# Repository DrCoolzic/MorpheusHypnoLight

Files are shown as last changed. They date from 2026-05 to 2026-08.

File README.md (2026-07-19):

# Morpheus HypnoLight

A low-cost Audio-Visual Stimulation (AVS) / Flicker Light Stimulation (FLS) device built around an ESP32-S3.

The device uses rhythmic light variation to influence brain activity and induce altered states of consciousness. It is controlled remotely via Bluetooth Low Energy or Wi-Fi, and can drive multiple LED groups with independent frequencies, waveforms, brightness, and phase modulation.

## Repository Structure

```text
MorpheusHypnoLight/
├── doc/                        # Project documentation
│   ├── MHLSpecification.md     # Product specification and features
│   ├── HardwarePrototype.md    # Prototype hardware, pinout, wiring, power budget
│   ├── SoftwareArchitecture.md # Firmware architecture and component design
│   ├── SoftwareSetup.md        # ESP-IDF + VS Code installation guide
│   └── images/                 # Diagrams, schematics, photos
├── firmware/                   # ESP-IDF firmware project
├── sim/                        # Simulation and PC-side tools
└── .venv/                      # Python virtual environment (for PC-side tools)
```

## Documentation

|Document|What you will find|
|---|---|
|[doc/MHLSpecification.md](doc/MHLSpecification.md)|Project objectives, features, LED architecture, oscillator design, sequence engine, real-time mode|
|[doc/HardwarePrototype.md](doc/HardwarePrototype.md)|Bill of materials, power supply, power budget, thermal design, ESP32-S3 pinout, wiring, main/control electronics, enclosure|
|[doc/SoftwareArchitecture.md](doc/SoftwareArchitecture.md)|Firmware layout, component responsibilities, data flow, build/flash instructions|
|[doc/SoftwareSetup.md](doc/SoftwareSetup.md)|Step-by-step installation of ESP-IDF, VS Code extension, and Hello World flash|

## Quick Start

1. Set up the development environment: follow [doc/SoftwareSetup.md](doc/SoftwareSetup.md).
2. Review the hardware prototype: [doc/HardwarePrototype.md](doc/HardwarePrototype.md).
3. Build and flash the firmware from the `firmware/` directory:

   ```bash
   cd firmware
   idf.py set-target esp32s3
   idf.py build
   idf.py -p PORT flash monitor
   ```

   In VS Code, use the ESP-IDF extension commands: **Build your Project**, **Flash your Project**, **Monitor your Device**.

## Hardware at a Glance

- **MCU**: ESP32-S3-DevKitC-1 (N16R8 module, 8MB PSRAM, 16MB flash)
- **LED drivers**: 3× SparkFun PicoBuck (AL8805, 9 channels total) for the prototype; final PCB will use AL8860 LED drivers
- **LEDs**: 32× 1W cold white (PB1..PB4 peripheral banks) + 4× 3W warm white (CG central group)
- **Power**: 24V / 5A supply, 5V buck converter for the ESP32
- **Cooling**: PWM-controlled fan driven by a TMP36 temperature sensor
- **Control interface**: 4× Adafruit NeoRotary 4 (I2C rotary encoders) + 1× I2C OLED display

## Status

This project is currently in the **hardware prototype and firmware architecture** phase. The specification and hardware documentation are in place; the firmware is under development. Once the prototype is validated, a dedicated `HardwarePCB.md` document will cover the final PCB design and production files.

## License

- Firmware and documentation: [MIT License](LICENSE)
- Hardware designs and production files: [CERN Open Hardware Licence v2 — Permissive](LICENSE-HARDWARE)

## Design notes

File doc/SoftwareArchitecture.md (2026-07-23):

# Software Architecture

## Overview

The Morpheus HypnoLight firmware is an [ESP-IDF](https://docs.espressif.com/projects/esp-idf/en/latest/esp32s3/index.html) project located in the `firmware/` directory of the repository. It is structured as a set of ESP-IDF components, each responsible for a distinct part of the device behavior.

The firmware implements two main operating modes described in the product specification:

- **Player Mode**: the `sequence` component advances stored steps and sends parameters to the `led_engine`.
- **Editor Mode**: commands from the `comms` layer or local controls write parameters directly into the `led_engine`.

Both modes share the same `led_engine` signal generation pipeline, which contains per oscillator a frequency modulator, a brightness modulator, and an oscillator.

## Repository Layout

```text
firmware/
├── CMakeLists.txt          # Project declaration
├── sdkconfig               # Generated menuconfig, committed to git
├── sdkconfig.defaults      # Optional baseline configuration
├── main/                   # Application entry point
│   ├── CMakeLists.txt
│   └── main.c              # app_main(): initialization
└── components/             # Application components
    ├── oscillator/         # Software oscillator engine (LUT + DDS)
    ├── led_control/        # Fixed LEDC channel output
    ├── modulator/          # Generic static/linear/LFO value generator
    ├── led_engine/         # Per-oscillator control chain
    ├── sequence/           # Sequence engine (steps, playback)
    └── comms/              # BLE / Wi-Fi communication layer
```

## Components

### `oscillator`

Responsible for generating the five low-frequency signals that drive the four peripheral banks (PB1..PB4) and the central group (CG).

- **Waveforms**: sine, square, triangle, custom.
  - **Sine** and **custom** are pre-computed into a 64-sample LUT when static parameters change.
  - **Square** and **triangle** are generated directly from the phase accumulator and duty cycle each tick.
- **Static parameters per oscillator**: waveform and phase. They are applied at a sequence-step boundary through `oscillator_set_static()`; sine and custom rebuild the LUT, while square and triangle only store the new waveform and phase.
- **Dynamic parameters per oscillator**: frequency and duty cycle. Both are updated on the fly through `oscillator_set_frequency()` and `oscillator_set_duty_cycle()` without rebuilding any LUT.
- **Output**: normalized instantaneous waveform values `osc_values[5]` in the range `[0.0, 1.0]`. At 0 Hz, an oscillator returns a constant `1.0` regardless of waveform, phase, or duty cycle.
- **Implementation**: Direct Digital Synthesis (DDS) phase accumulator updated by `oscillator_tick()` at 1 kHz. Sine and custom use a 64-sample LUT; square and triangle are computed from phase and duty. The component is independent of LEDC and brightness control.
- **Public API**:
  - `esp_err_t oscillator_init(void)`
  - `esp_err_t oscillator_set_static(uint8_t oscillator_id, const oscillator_static_config_t *config)`
  - `esp_err_t oscillator_set_frequency(uint8_t oscillator_id, float frequency_hz)`
  - `esp_err_t oscillator_set_duty_cycle(uint8_t oscillator_id, float duty_cycle)`
  - `esp_err_t oscillator_tick(float osc_values[OSCILLATOR_COUNT])`

### `led_control`

Converts the normalized oscillator waveform and current brightness into the duty cycle written to the five fixed LEDC hardware channels, applying a gamma correction so that brightness ramps appear perceptually linear. It does not evaluate step timing, interpolation, or LFOs.

- **PB1–PB4**: LEDC channels 0–3 at a common carrier frequency and 10-bit resolution. Each channel controls the two LED sub-groups in its peripheral bank.
- **CG**: LEDC channel 4, using the same configuration as the peripheral banks.
- **Fixed mapping**: API oscillator IDs 0–3 map to PB1–PB4 / LEDC channels 0–3; ID 4 maps to CG / LEDC channel 4.
- **Duty calculation**: `final_duty = osc_value × gamma(current_brightness × global_brightness)`, where `gamma(x) = x^2.2` approximates the human eye response so that linear brightness ramps look perceptually smooth. All inputs are normalized to `[0.0, 1.0]`, and out-of-range values are clamped; invalid oscillator IDs and non-finite input values return an error.
- **LED off condition**: a `current_brightness` of `0.0` turns the oscillator off regardless of waveform, frequency, phase, or duty cycle.
- **Global brightness multiplier**: configurable at runtime through `led_control_set_global_brightness()`. The default is 1.0 (no attenuation). A single setting scales the overall lamp brightness; the test application sets it to 0.5 to limit eye strain.
- **Public API**:
  - `esp_err_t led_control_init(void)`
  - `esp_err_t led_control_update(uint8_t oscillator_id, float osc_value, float current_brightness)`
  - `esp_err_t led_control_set_global_brightness(float brightness)`
  - `float led_control_get_global_brightness(void)`
  - `esp_err_t led_control_all_off(void)`

### `sequence`

Step sequencer / playback engine. The realtime parameter evaluation previously implemented here has moved to the `led_engine` component. `sequence` now focuses on storing and advancing steps, then dispatching per-oscillator modulator configurations to `led_engine`.

- **Player mode**: reads a stored sequence and advances from step to step. Each step carries duration, static oscillator configuration, and modulator settings for frequency, brightness, and duty cycle.
- **Editor mode**: future commands from `comms` will write step data and playback commands into `sequence`.
- **Playback control**: play, pause, seek, loop, and tempo will be managed here.
- **Public data types**:
  - `sequence_step_t` with `duration_ms` and per-oscillator `sequence_oscillator_step_t`
  - `sequence_oscillator_step_t` with `oscillator_static_config_t` and `modulator_config_t` for `frequency_modulator`, `brightness_modulator`, and `duty_modulator`
- **Public API**:
  - `esp_err_t sequence_init(void)`
  - `esp_err_t sequence_load(const sequence_step_t *steps, uint32_t step_count)`
  - `esp_err_t sequence_play(void)`
  - `esp_err_t sequence_pause(void)`
  - `esp_err_t sequence_seek(uint32_t position_ms)`
  - internal timer drives `sequence_tick()` every `SEQUENCE_STEP_TICK_PERIOD_MS`
  - `bool sequence_is_playing(void)`
  - `uint32_t sequence_get_current_step(void)`

### `modulator`

Generic time-varying value generator used by `led_engine` for frequency and brightness. It supports three modes: `static`, `linear`, and `lfo`. The LFO has no LUT and supports sine (or a triangle approximation) and square with a fixed 50% duty cycle.

```c
/** @brief Modulator operating modes. */
typedef enum {
  MODULATOR_MODE_STATIC,
  MODULATOR_MODE_LINEAR,
  MODULATOR_MODE_LFO,
} modulator_mode_t;

/** @brief LFO waveforms supported by the modulator. */
typedef enum {
  MODULATOR_LFO_WAVEFORM_SINE,
  MODULATOR_LFO_WAVEFORM_SQUARE,
} modulator_lfo_waveform_t;

/** @brief Static mode configuration: a constant value. */
typedef struct {
  float value;
} modulator_static_config_t;

/** @brief Linear mode configuration: ramp from start to end over a duration. */
typedef struct {
  float start_value;
  float end_value;
  uint32_t duration_ms;
} modulator_linear_config_t;

/** @brief LFO mode configuration. */
typedef struct {
  modulator_lfo_waveform_t waveform;
  float frequency_hz;
  float low;
  float high;
} modulator_lfo_config_t;

/** @brief Complete modulator configuration. */
typedef struct {
  modulator_mode_t mode;
  modulator_static_config_t static_config;
  modulator_linear_config_t linear_config;
  modulator_lfo_config_t lfo_config;
} modulator_config_t;

/** @brief Modulator runtime state. */
typedef struct {
  modulator_config_t config;
  float current_value;
  float start_value;
  uint32_t elapsed_ms;
  float lfo_phase;
} modulator_state_t;

/** @brief Initialize a modulator to static zero. */
esp_err_t modulator_init(modulator_state_t *state);

/** @brief Apply a new configuration and capture internal start state. */
esp_err_t modulator_set_config(modulator_state_t *state, const modulator_config_t *config);

/** @brief Compute the next value after delta_time_ms. */
esp_err_t modulator_evaluate(modulator_state_t *state, float delta_time_ms, float *value);
```

### `led_engine`

Encapsulates the per-oscillator signal chain: a frequency modulator, a brightness modulator, and an oscillator. It receives parameter updates from `sequence` in Player mode or directly from `comms` / local controls in Editor mode, then drives `led_control`.

- **Per oscillator**:
  - `frequency_modulator`: instance of the `modulator` component. Output is in Hz and forwarded to `oscillator_set_frequency()`.
  - `brightness_modulator`: instance of the `modulator` component. Output is normalized `[0.0, 1.0]` and forwarded to `led_control_update()` as `current_brightness`; `led_control` treats it as a perceptual brightness value and applies a gamma correction.
  - `duty_modulator`: instance of the `modulator` component. Output is normalized `[0.0, 1.0]` and forwarded to `oscillator_set_duty_cycle()`.
  - `oscillator`: generates the waveform from `oscillator_static_config_t`, the current frequency, and the current duty cycle.
- **Evaluation**: at each 1 kHz tick the engine evaluates the frequency, brightness, and duty modulators, applies them through `oscillator_set_frequency()` and `oscillator_set_duty_cycle()`, then calls `oscillator_tick()`, and passes `osc_value` and `brightness` to `led_control_update()`.
- **Public API**:
  - `esp_err_t led_engine_init(void)`
  - `esp_err_t led_engine_set_static(uint8_t oscillator_id, const oscillator_static_config_t *config)`
  - `esp_err_t led_engine_set_frequency(uint8_t oscillator_id, float frequency_hz)`
  - `esp_err_t led_engine_set_brightness(uint8_t oscillator_id, float brightness)`
  - `esp_err_t led_engine_set_duty_cycle(uint8_t oscillator_id, float duty_cycle)`
  - `esp_err_t led_engine_linear_frequency(uint8_t oscillator_id, float start_value, float end_value, uint32_t duration_ms)`
  - `esp_err_t led_engine_linear_brightness(uint8_t oscillator_id, float start_value, float end_value, uint32_t duration_ms)`
  - `esp_err_t led_engine_linear_duty_cycle(uint8_t oscillator_id, float start_value, float end_value, uint32_t duration_ms)`
  - `esp_err_t led_engine_set_frequency_modulator(uint8_t oscillator_id, const modulator_config_t *config)`
  - `esp_err_t led_engine_set_brightness_modulator(uint8_t oscillator_id, const modulator_config_t *config)`
  - `esp_err_t led_engine_set_duty_cycle_modulator(uint8_t oscillator_id, const modulator_config_t *config)`
  - `esp_err_t led_engine_tick(void)`
  - `esp_err_t led_engine_all_off(void)`

### `comms`

Communication layer for remote control and configuration.

- **Bluetooth Low Energy (BLE)**: primary control channel from the mobile/desktop application.
- **Wi-Fi**: optional web server interface for configuration and control.
- **Protocol**: to be defined (commands for play/pause/seek, parameter updates, sequence upload).
- **Public API** (to be defined):
  - `comms_init()`
  - `comms_register_command_handler(...)`
  - `comms_send_status(...)`

## Data Flow

The `led_engine` pipeline is shared by both Player and Editor modes. `sequence` (Player mode) and direct commands (Editor mode) both feed the same engine; the engine evaluates the frequency and brightness modulators, drives the oscillator, and writes the final duty cycle through `led_control`.

```mermaid
flowchart LR
    subgraph Sources
        RT([Realtime / Editor])
        SEQ([Sequence / Player])
    end

    RT -->|set parameters| CTRL
    SEQ -->|step parameters| CTRL

    subgraph CTRL[led_engine per oscillator]
        direction TB
        FM[frequency_modulator<br/>static / linear / lfo]
        BM[brightness_modulator<br/>static / linear / lfo]
        DM[duty_modulator<br/>static / linear / lfo]
        OSC[oscillator<br/>waveform, phase]
    end

    FM -- frequency_hz --> OSC
    DM -- duty_cycle --> OSC
    OSC -- osc_value --> LED
    BM -- brightness --> LED

    subgraph LED[led_control]
        direction TB
        PWM[LEDC PWM 1 kHz]
        DRV[AL8860 driver]
    end

    LED -->|PWM| LEDS[LED banks PB1..PB4 / CG]
```

## Runtime Architecture (FreeRTOS)

ESP-IDF includes FreeRTOS as the default real-time kernel. The firmware does not require a different RTOS such as Zephyr; FreeRTOS is sufficient for all timing, peripheral, and communication needs.

Proposed FreeRTOS tasks and timers:

|Task / Timer|Period|Responsibility|
|---|---|---|
|`led_engine_timer`|1 ms (1 kHz)|Call `led_engine_tick()` to evaluate frequency, brightness, and duty modulators, apply `oscillator_set_frequency()` / `oscillator_set_duty_cycle()`, advance the oscillator, and pass each waveform value and effective brightness to `led_control`.|
|`sequencer_task`|10–50 ms|Future sequence playback: advance stored steps and dispatch modulator configurations to `led_engine`.|
|`input_task`|50–100 ms|Poll I2C rotary encoders and update parameters or sequence.|
|`display_task`|100–250 ms|Refresh the OLED display with current status.|
|`comms_task`|event-driven|Handle BLE/Wi-Fi events and dispatch commands.|
|`fan_task`|1 s|Read TMP36 temperature, update fan PWM.|
|`watchdog_task`|1 s|Feed the watchdog and monitor safety thresholds (temperature, stack).|

**Inter-task communication:**

- `led_engine` protects its per-oscillator modulator configuration with a critical section. Modulator evaluation, frequency publication to `oscillator`, oscillator ticking, and LED output updates happen sequentially in the 1 kHz timer callback.
- `led_control` protects the global brightness multiplier with a critical section; the final output is scaled in `led_control_update()`.
- `comms` posts commands to a FreeRTOS queue consumed by `sequence` or `input_task`.

## Build, Flash and Monitor

All commands are run from the `firmware/` directory.

```bash
idf.py set-target esp32s3
idf.py build
idf.py -p PORT flash
idf.py -p PORT monitor
```

For Visual Studio Code, use the ESP-IDF extension commands:

- **ESP-IDF: Build your Project**
- **ESP-IDF: Flash your Project**
- **ESP-IDF: Monitor your Device**

> **Important:** Always use the **`UART`** USB port of the DevKitC-1 for flashing and monitoring. See [SoftwareSetup.md](SoftwareSetup.md) for the full environment setup.

## Important `sdkconfig` Settings

The following ESP-IDF configuration options will be required or important for the project. They are typically set via `idf.py menuconfig` and committed in `sdkconfig`:

- **LEDC**: 5 channels, 10-bit resolution, using a common carrier frequency for PB1..PB4 and CG.
- **I2C**: master mode on GPIO1 (SDA) / GPIO2 (SCL) for the QWIIC bus.
- **ESP Timer**: periodic task-dispatched callback at 1 kHz for `oscillator_tick()` and LEDC output updates. The application does not rely on the FreeRTOS tick rate for oscillator timing.
- **BLE / Wi-Fi**: enable as needed for the `comms` component.

## Testing

### Visual Hardware Test

The current `main` application includes a visual oscillator test using a single task-dispatched `esp_timer` callback at 1 kHz. The callback calls `led_engine_tick()`, which evaluates the frequency and brightness modulators, advances the oscillator, and updates `led_control`. Linear ramps are therefore evaluated each millisecond inside the modulators.

The test stages use full per-channel brightness values; the global brightness multiplier is set to 0.5 in `app_main()` (`led_control_set_global_brightness(0.5f)`), scaling the effective output to 50% to reduce eye strain:

- PB1: 2 Hz square waveform with 50% duty cycle (set dynamically via `led_engine_set_duty_cycle()`).
- PB2: 2 Hz square waveform with 25% duty cycle (set dynamically via `led_engine_set_duty_cycle()`).
- PB3: 0.25 Hz triangle waveform.
- PB4: 0.25 Hz sine waveform.
- CG: 0 Hz fixed output, independent of waveform and phase.
- PB1 and PB2: 2 Hz square waveforms with a 180-degree phase offset.
- PB1: linear brightness ramp from 0% to 100% over 4 seconds at 0 Hz.
- PB2: linear frequency ramp from 0 Hz to 2 Hz over 4 seconds at full per-channel brightness.

This validates the oscillator-to-LEDC pipeline on hardware, including waveforms, duty cycle, frequency, zero-frequency behavior, relative phase, and visible realtime linear ramps. It does not replace deterministic unit tests of individual LUT samples, DDS phase increments, or sequence tick interpolation.

### Deferred Unit Tests

A future ESP-IDF Unity test application will be separate from the production firmware. It will build and flash independently, then run Unity `TEST_CASE` functions over the serial monitor. The first oscillator unit tests should cover initialization, zero-frequency output, waveform phase, DDS phase advancement, custom LUT copying, and argument validation.

## TBD / Future Sections

- Sequence file format (JSON or binary).
- BLE/Wi-Fi command protocol.
- Error handling and safety (thermal shutdown, watchdog).
- Fan control algorithm.
- Calibration and factory settings.

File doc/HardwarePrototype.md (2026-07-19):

# Hardware Prototype

The prototype is built on a set of boards connected via QWIIC/STEMMA QT cables:

- **Main electronics**: ESP32-S3-DevKitC-1, 3× PicoBuck LED converters, 9 LED groups, temperature sensor, fan, 2× DC-DC converters (for 5V and 12V)
- **Control electronics**: 4× Adafruit NeoRotary 4 (I2C quad rotary encoder + NeoPixel ring), 1× I2C OLED display 128×64 SSD1306

## Components

The components used for the prototype are:

- [ESP32-S3-DevKitC-1 8MB PSRAM 16MB FLASH N16R8 42Pin](https://fr.aliexpress.com/item/1005007173771226.html) development board
- 3× [PicoBuck LED Driver](https://www.sparkfun.com/picobuck-led-driver.html)
- 32× [1W High Power cool white 6500K LED with 20mm star pcb](https://fr.aliexpress.com/item/1005003381591196.html) for the 8 peripheral groups
- 4× [3W High Power warm white LED with 20mm star pcb](https://fr.aliexpress.com/item/1005003381591196.html) for the central group
- [150×150 aluminum plate](https://www.amazon.fr/Plaque-aluminium-5083-150mm/dp/B07NYV688B/ref=sr_1_6?th=1) (or a [150×150×25mm Aluminum Heat Sink radiator](https://fr.aliexpress.com/item/32958588818.html))
- [ARCTIC TP-4 : High Performance Thermal Pad 100×100×0.5 mm](https://www.amazon.fr/ARCTIC-TP-4-thermique-performance-irrégularités/dp/B0FZV47ZNR/ref=sxin_10_pa_sp_search_thematic_sspa?th=1)
- [24V 5A 120W Power Supply](https://www.amazon.fr/Alimentation-Adaptateur-Transformateur-Convertisseur-Surveillance/dp/B0FWRG2X67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)
- [5A DC-DC Step Down Power Supply Buck Converter](https://fr.aliexpress.com/item/1005005921557535.html) for 5V ESP32 power
- [12V DC-DC Step Down Power Supply Buck Converter](https://fr.aliexpress.com/item/1005010319587802.html) for 12V fan power
- [TMP36 temperature sensor](https://fr.aliexpress.com/item/1005007666012953.html)
- [4-pin SM04B-SRSS-TB connector for QWIIC](https://fr.aliexpress.com/item/1005012597457629.html)
- [2.54 mm KF2510 3+1P KF2510-4AW Male Housing Connector White Straight Pin Header 4pin](https://fr.aliexpress.com/item/1005004714218238.html)
- 4× [Adafruit I2C Quad Rotary Encoder](https://learn.adafruit.com/adafruit-i2c-quad-rotary-encoder-breakout/arduino)
- [I2C OLED Display 128×64 SSD1306](https://fr.aliexpress.com/item/1005011852817482.html)

> **Note:** The PicoBuck uses the AL8805 LED driver, which is functionally equivalent to the AL8860 selected for the final product. The AL8860 is the recommended choice for the final PCB design.
>

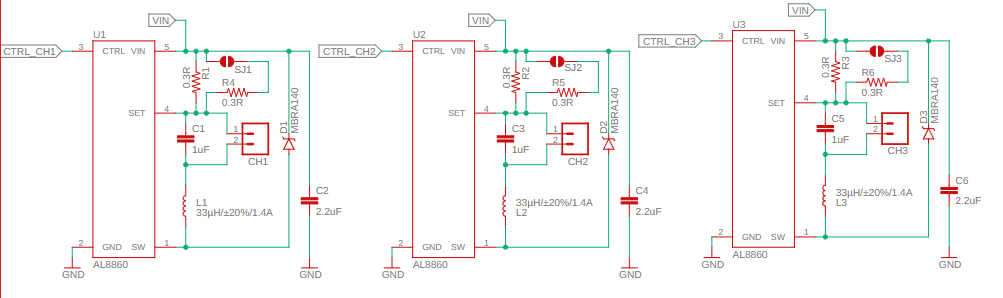
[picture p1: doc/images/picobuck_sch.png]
PicoBuck Schematic


## Power Supply

The prototype is powered by a 24V 5A 120W supply:

- 24V is used directly by the PicoBuck LED Buck Converters to power the LEDs.
- A 5V DC-DC buck converter provides power to the ESP32-S3-DevKitC-1.
- A 12V DC-DC buck converter provides power to the PWM fan.

> **Important — Power source conflict:** The ESP32-S3-DevKitC-1 can be powered either from the on-board USB port(s) or from the external `5V` pin, but these two sources are mutually exclusive. If the 5V DC-DC converter is connected to the DevKit `5V` pin while the USB cable is also plugged in, the USB 5V rail and the converter output will be in parallel. Depending on the converter design, this may cause backfeeding and could damage the converter or the USB port.
>
> **Always isolate the 5V DC-DC converter output (e.g., with a jumper) before connecting a USB cable for development.**

## Power Budget

|Component|Power|Notes|
|---|-----|-----|
|8 peripheral LED groups|~36W|4 × 1W cold white LEDs per group|
|Central LED group|~4.5W|4 × 3W warm white LEDs at ~330mA (default)|
|Central LED group (strap)|~9W|Same LEDs at ~660mA with current-doubling strap|
|LED driver losses|~4W|~10% buck converter losses at full LED power|
|ESP32-S3 + peripherals|~2.5W|Dev board at 5V, ~500mA peak|
|5V buck converter|~0.5W|Conversion losses|
|12V buck converter|~0.5W|Conversion losses for the fan|
|PWM fan|~1W|120mm fan at moderate speed|
|**Total (default)**|**~49W**|Corresponds to ~2.0A at 24V|
|**Total (central strap)**|**~54W**|Corresponds to ~2.3A at 24V|

The 24V / 5A / 120W supply leaves a comfortable margin (about 2.5× the expected maximum load).

## Thermal Considerations

At full brightness, the LEDs dissipate most of their consumed power as heat. The 150×150mm aluminum plate (or optional heatsink) combined with the PWM fan must keep the LED temperature below the rated maximum. The TMP36 temperature sensor located on the aluminum LED plate will increase the fan speed if the temperature exceeds a defined threshold. Exact thermal calculations will depend on the final plate thickness, heatsink choice, and ambient conditions, and will be validated during prototype testing.

## ESP32-S3 Pin selection

The following pins must **not** be used as general-purpose I/O:

- **GPIO0**: Strapping pin — boot mode selection (download vs. normal boot)
- **GPIO3**: Strapping pin — JTAG signal source selection
- **GPIO45**: Strapping pin — VDD_SPI voltage (3.3 V vs 1.8 V for flash/PSRAM)
- **GPIO46**: Strapping pin — ROM serial output enable
- **GPIO19**: USB D- (USB-JTAG); disables USB-JTAG if reconfigured
- **GPIO20**: USB D+ (USB-JTAG); disables USB-JTAG if reconfigured
- **GPIO26–GPIO32**: Reserved for internal SPI0/1 flash — never use
- **GPIO33–GPIO37**: Reserved for Octal flash/PSRAM — **this project uses an ESP32-S3R8 module**, so all five pins are unavailable externally.
- **GPIO43**: UART0 TX (wired to the on-board USB-to-UART bridge CP2102N) — avoid unless UART0 is not needed
- **GPIO44**: UART0 RX (same as above)
- **GPIO48**: On-board addressable RGB LED

> **Note on GPIO39–42:** These are **safe to use** as general-purpose I/O (they are JTAG pins only when the JTAG interface is actively enabled via software/OpenOCD, not by default in application code).

For the prototype we need 10 GPIO pins:

- 4 LEDC/PWM GPIO pins for the signals that control the 4 peripheral banks (PB1-PB4), each containing 2 LED sub-groups: GPIO4, GPIO5, GPIO6, GPIO7
- 1 LEDC/PWM GPIO pin for the signal that controls the central LED group (CG): GPIO15
- 2 I2C GPIO pins for the SDA/SCL signals that go to the QWIIC connector: GPIO1 (SDA), GPIO2 (SCL)
- 1 Analog GPIO pin connected to the TMP36 temperature sensor: GPIO16 (ADC2_CH5)
- 1 GPIO pin for fan tachometer input: GPIO17
- 1 GPIO pin to control the fan PWM: GPIO18

## Prototype wiring

The prototype consists of two electronics assemblies connected via QWIIC/STEMMA QT cables:

- **Main electronics**: ESP32-S3-DevKitC-1, PicoBuck converters, LED star groups, fan, temperature sensor
- **Control electronics**: 4× Adafruit NeoRotary 4 (I2C quad rotary encoder + NeoPixels), 1× I2C OLED display

### Main electronics

**Composed of**:

- An 15x15 cm aluminum plate with
  - [x] 36 (9x4) LEDs mounted with thermal pad
  - [ ] a temperature sensor
  - [x] One 6x9 cm prototype board with
    - [x] An ESP32-S3 devkit,
    - [x] A 5V DC-DC Buck converter
    - [x] A 5V Jumper so the converter can be isolated when a USB cable is plugged in for development
    - [ ] A 12V DC-DC Buck converter
    - [x] A 2 Pin power connector
    - [ ] A 4 pins QWIIC connector
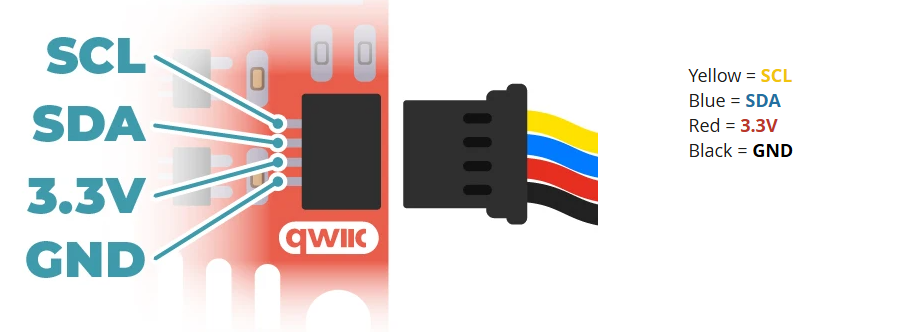
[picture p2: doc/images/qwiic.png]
QWIIC connector
    
    - [ ] A 4 pins PWM fan connector
    Fan connector
  - [x] Three PicoBuck boards
  - [x] Five 10 kΩ pull-down resistors on the LEDC/PWM control lines

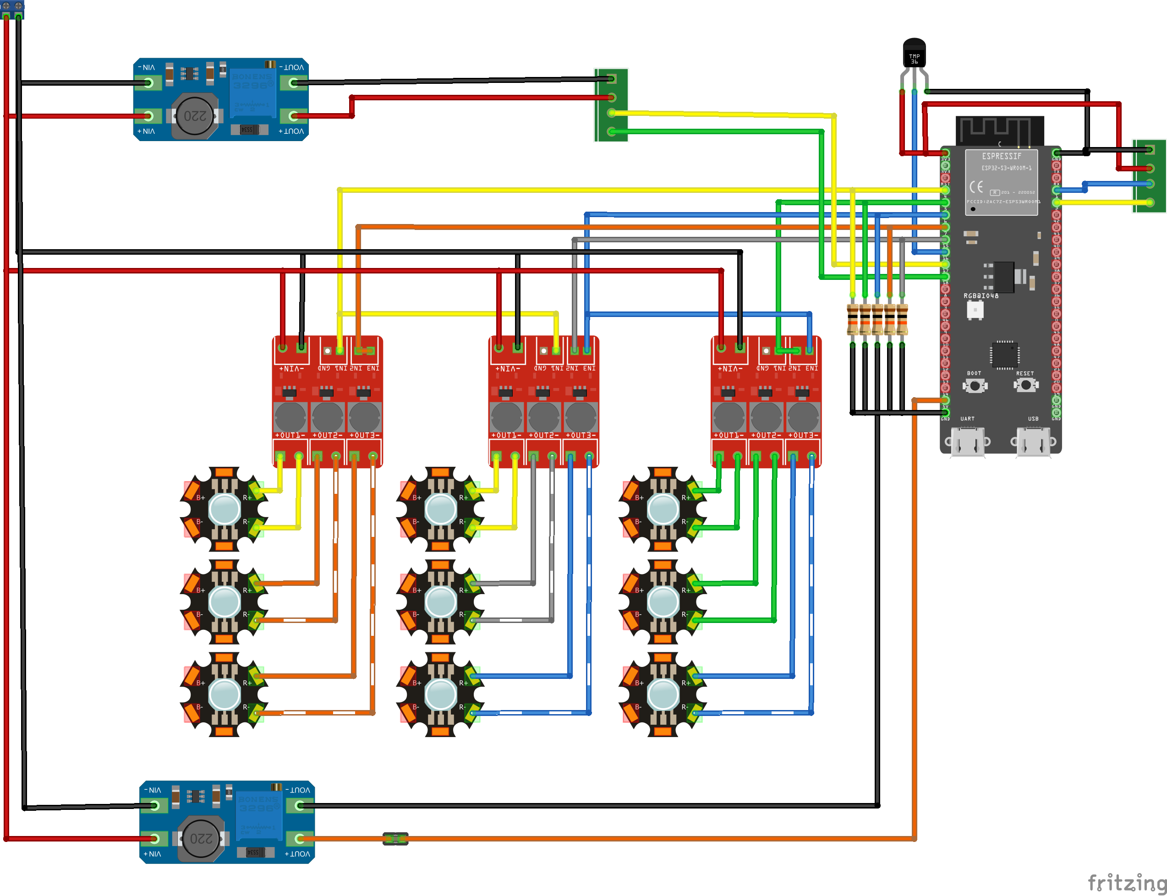
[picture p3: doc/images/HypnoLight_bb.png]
Main Electronics

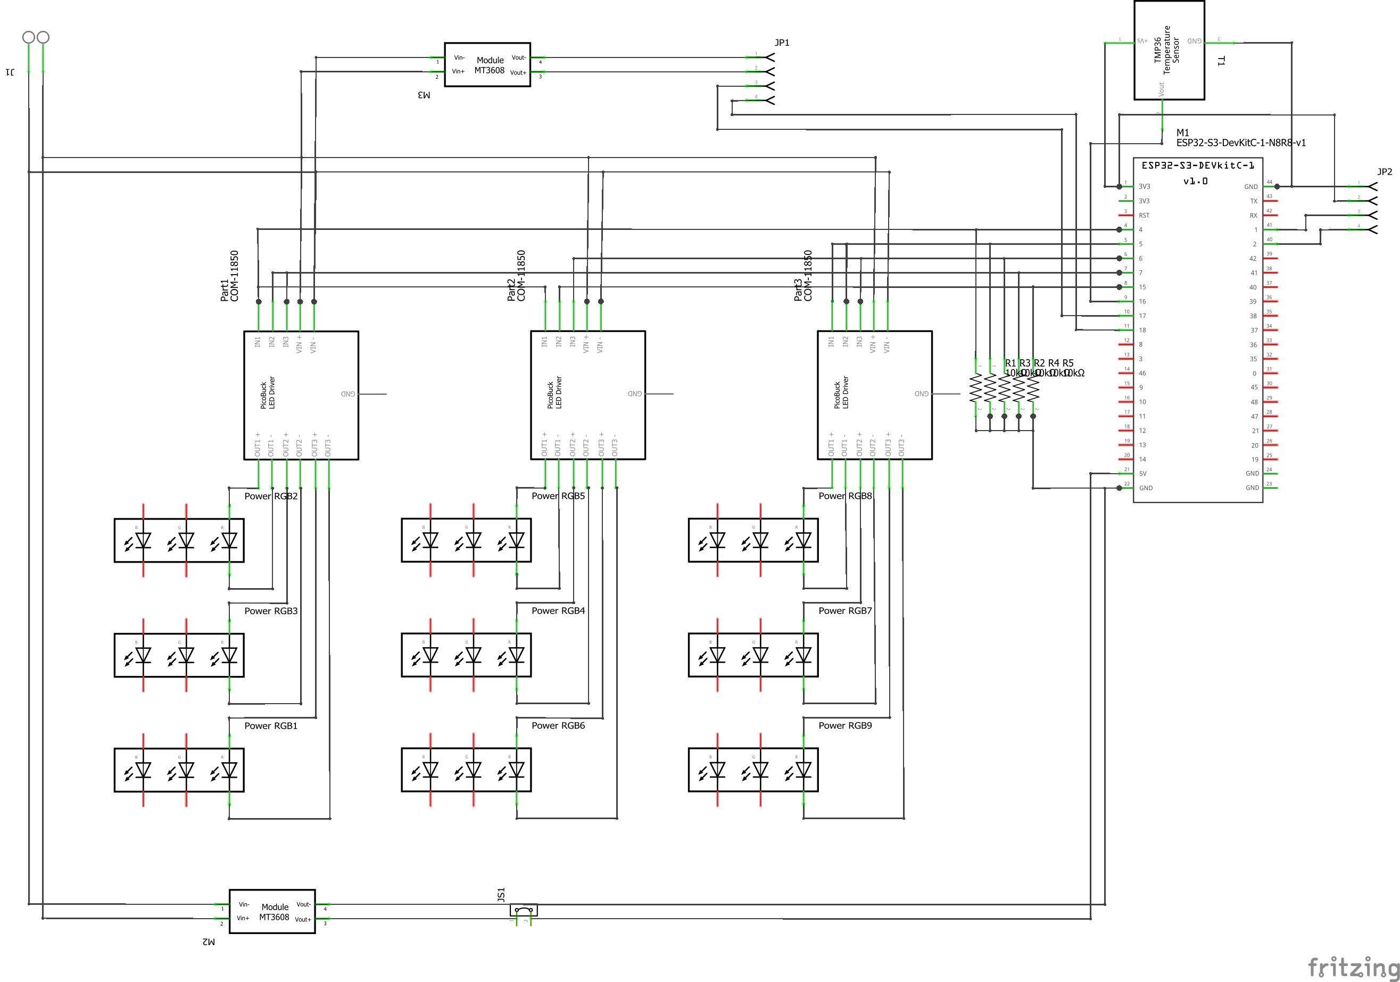
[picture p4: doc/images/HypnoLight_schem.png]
Main Schematic


> **Note1**: LED Groups are shown in the schematic as one LED but in fact each group contains 4 LEDs connected in series as shown below
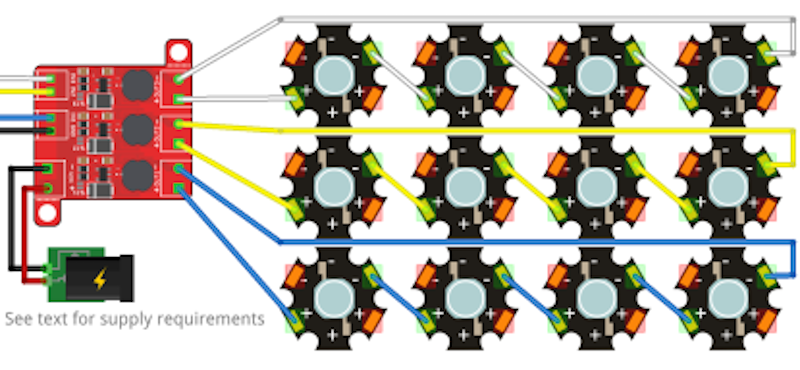
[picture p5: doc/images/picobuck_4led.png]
4LED


**Wiring**:

- [x] Connect the 24 V power supply to the input of the 3 PicoBuck converter (VIN+ / VIN−) using 18 AWG wires
- [ ] Connect the 24 V power supply to prototype board power connector
- [x] Connect the power connector to the 5V DC-DC converter inputs
- [ ] Connect the power connector to the 12V DC-DC converter inputs
- [x] Connect the 5V DC-DC converter GND output to the GND pins of the ESP32-S3-DevKitC-1
- [x] Connect the 5V DC-DC converter 5V output to the jumper input and the jumper output to the 5V pins of the ESP32-S3-DevKitC-1
- [x] Connect in series the 4 LEDs of each group of LEDs (nine) using 22 AWG wires
- [x] Connect the three outputs of the three PicoBuck the the nine group of LEDs using 22 AWG wires
- [x] Connect the inputs of the PicoBuck to the GPIO pins using 22 AWG wires
  - [x] GPIO4 to PicoBuck_1 IN1 and PicoBuck_2 IN1
  - [x] GPIO5 to PicoBuck_3 IN1 and IN2
  - [x] GPIO6 to PicoBuck_2 IN3 and PicoBuck_3 IN3
  - [x] GPIO7 to PicoBuck_1 IN2 and IN3
  - [x] GPIO15 to PicoBuck_2 IN2
  - [x] Connect one 10 kΩ pull-down resistor from each LEDC/PWM control line (GPIO4, GPIO5, GPIO6, GPIO7, GPIO15) to GND
  - [x] Connect the GND pins of the PicoBuck converters to the GND pin(s) of the ESP32-S3-DevKitC-1

> **PWM safety note:** During ESP32 reset and boot, the LEDC/PWM GPIOs are high impedance until the firmware configures them. The 10 kΩ pull-down resistors hold the PicoBuck inputs low during this interval, preventing an unintended full-brightness flash.

- [ ] For the QWIIC connector: Connect SDA to GPIO1, SCL to GPIO2, VCC to 3.3 V, GND to GND.
- [ ] For the PWM Fan Connector: Connect the 12V DC-DC converter outputs to the V+ and GND pins, TACH pin to GPIO17, PWM pin to GPIO18
- [ ] Connect the temperature sensor power and ground to the 3.3V and GND pins of the ESP32
- [ ] Connect the temperature sensor output to GPIO16

### Control electronics

The Control electronics is a standalone device connected to the Main electronics via a QWIIC/STEMMA QT cable. All components on this device communicate with the ESP32-S3 over the shared I2C bus (GPIO1/GPIO2).

**Components (to be connected in a later prototype phase):**

> **Note:** The NeoRotary encoders and OLED display are not connected in the first hardware bring-up phase. The initial firmware will be controlled and monitored via the serial interface.

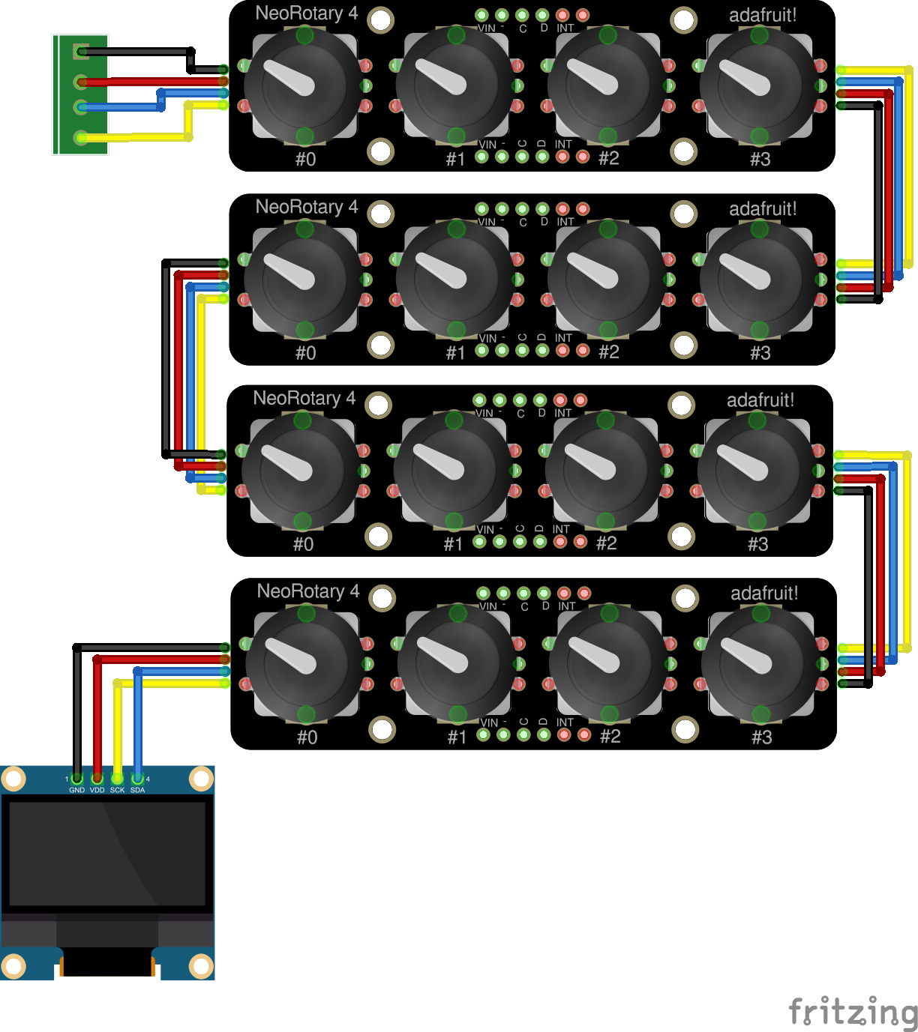
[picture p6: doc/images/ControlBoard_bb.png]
Control


**I2C addressing:**

The four NeoRotary 4 boards share the same I2C bus. Each board's address must be unique and set via the address jumpers on the board:

|Board|I2C Address|
|-----|---|
|NeoRotary #0|0x49 (default)|
|NeoRotary #1|0x4A|
|NeoRotary #2|0x4B|
|NeoRotary #3|0x4C|
|OLED display|0x3C (typical)|

**Wiring:**

- [ ] Mount the four NeoRotary 4 boards on the Control electronics board.
- [ ] Mount the OLED display on the Control electronics board.
- [ ] Chain all boards via their QWIIC connectors (daisy-chain): Main electronics → NeoRotary #0 → NeoRotary #1 → NeoRotary #2 → NeoRotary #3 → OLED.
- [ ] Set the I2C address jumpers on each NeoRotary 4 board according to the table above.
- [ ] Connect the first QWIIC connector of the chain to the QWIIC connector on the Main electronics.

## Enclosure Prototype

> **Note:** The enclosure will differ between the prototype and the final product.

The main prototype enclosure will be designed to hold the Main electronics, the LED plate, and the cooling fan.
The control enclosure will be designed to hold the Control electronics.

The current plan is to use FreeCAD with MCP to generate the enclosure and drive a 3D printer.

TBD.

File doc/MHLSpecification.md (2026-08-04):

# Morpheus HypnoLight Device

## Objective

The Morpheus HypnoLight Project is an ecosystem consisting of three main components: the Morpheus Player, the Morpheus Editor, and the Morpheus HypnoLight Device.
The objective of this project is to create an environment for visual and auditory stimulation often referred to as AVS (Audio-Visual Stimulation) or FLS (Flicker Light Stimulation).
Flicker Light Stimulation is a non-invasive technique that uses rhythmic light variation to influence brain activity and the state of consciousness.
It involves emitting rhythmic light pulses at specific frequencies, typically ranging from 3 Hz to 50 Hz.
These light pulses stimulate the visual system, leading to a phenomenon called "visual entrainment," in which brain activity synchronizes with the frequency of the light.
This synchronization can induce altered states of consciousness, like those experienced during deep meditation or under the influence of psychedelics, often accompanied by striking visual patterns and sensations beyond conscious control.

A stimulation session consists of both an acoustic component and a visual component.
The audio component is handled by the Morpheus Player / Editor, and the visual component is handled by the Morpheus HypnoLight device.

This specification describes the Morpheus HypnoLight Device, which generates light flashes controlled by the Morpheus Player or the Morpheus Editor.

## Operating Modes

The Morpheus HypnoLight Device can be controlled by two host applications, each corresponding to a distinct operating mode:

**Player Mode**

When controlled by the Morpheus Player, the device behaves like a video player: it loads and plays a sequence made of steps. Playback follows the timing defined in the sequence, and the Player handles the audio locally while sending the necessary timing and parameter data to the HypnoLight device. When playback is paused, the LEDs turn off. This mode is intended for end users who are not concerned with the internal content of the sequence.

**Editor Mode**

When controlled by the Morpheus Editor, the device supports both sequence playback and realtime editing. While a sequence is playing, the behavior is similar to Player mode. When the Editor is paused, playback stops and the current LED state is frozen (the LEDs remain on). The user then enters a realtime editing state in which any parameter — such as oscillator frequency, waveform, duty cycle, phase, or brightness — can be modified directly, for example through potentiometers or on-screen controls. Changes are applied immediately and are reflected on the LEDs in real time. This mode is intended for users who create and edit sequences and therefore need a detailed understanding of how the Morpheus HypnoLight device works.

---

## Main Features

- Two modes of operation as described above
- Bluetooth Low Energy connectivity, used to connect to the control applications and potentially to a sound system
- 4 peripheral LED banks (PB1..PB4, cold white), each containing 2 sub-groups of 4 LEDs and driven by one of 4 LEDC hardware channels
- 1 central LED group (CG, warm white) driven by a dedicated LEDC hardware channel
- 5 oscillators with sine, triangle, square, and custom waveforms, each with controllable frequency, duty cycle, brightness, and phase; oscillators 1-4 drive banks PB1-PB4 and oscillator 5 drives the central group CG
- Generic modulator for frequency, brightness, and duty cycle with static, linear, and simple LFO modes
- Step-based sequence engine with modulator-based frequency, brightness, and duty cycle control
- Capability to freely pause and seek loaded sequences
- A gamma correction is applied to compensate for the fact that the brightness perceived by the human eye follows the Weber–Fechner law, making variations in brightness appear linear.
- Low-cost hardware (target: under $100)
- Low-noise cooling using a large PWM temperature controlled fan
- Compact and easy to carry with [tripod mounting threads](https://www.amazon.fr/ruthex-Lot-pannes-%C3%A0-souder/dp/B0F1B8GC7Z?th=1) - [Hexagonal Insert for Tripod Mounting](https://www.amazon.fr/QUARKZMAN-Entra%C3%AEnement-Hexagonal-Connecteur-Fixation/dp/B0G138HB36/ref=sr_1_49_sspa)
- WiFi web server interface

---

## LED PCB

The LEDs are placed on a front panel PCB with an aluminum substrate for heat dissipation. In addition to the LEDs, the PCB contains temperature sensors that automatically activate the fan if the device overheats.

Numerous experiments have shown that the position of the LEDs on the PCB has no effect on the user's perception. For instance, a diode that lights up in the top left or bottom right corner of the board is perceived by the user in exactly the same way. Consequently, the LEDs have been arranged into four peripheral banks (PB1..PB4) plus one central group (CG), with each bank containing two sub-groups of four LEDs each:

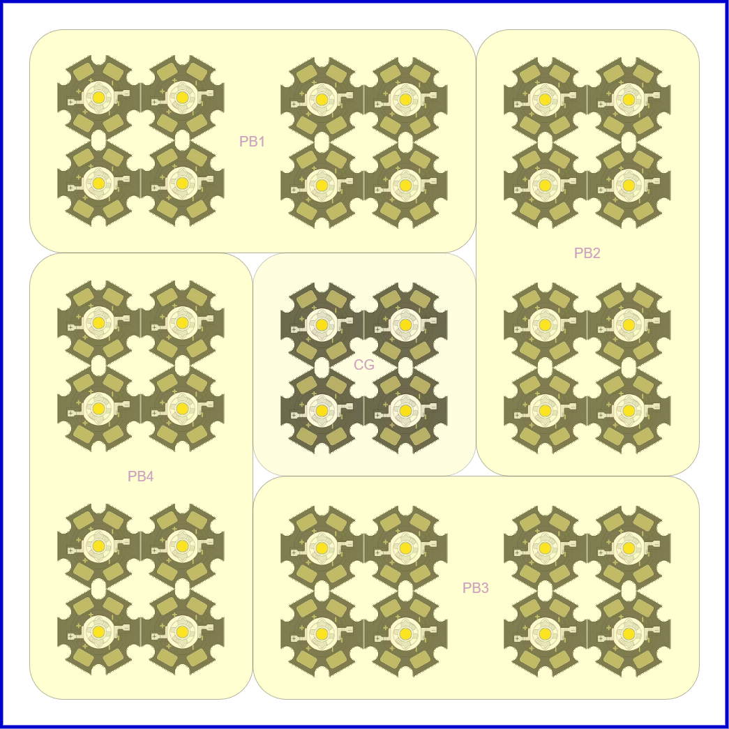
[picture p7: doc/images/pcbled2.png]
Led


The four peripheral banks are connected to four oscillators, each of which has adjustable frequency, brightness, and duty cycle settings. They use cold **white** LEDs with a power rating of approximately one watt each (with a current of about 330 mA). Therefore, each sub-group driven with a current of 330 mA can provide a maximum power output of 4.5 watts, for a total output of about 36 watts for all eight sub-groups combined.

The central group uses four **warm** white LEDs rated at 3 W each but driven at about 2W (with a current of about 660 mA). Therefore, the central group can provide a maximum power output of 9 watts,

---

## LED Control Architecture

### Overview

The device drives 9 physical LED driver channels (eight peripheral sub-groups and the central group) using a single control path:

- **5 software oscillators** drive 5 LEDC hardware channels of the ESP32-S3.
- **Oscillators 1-4** drive the 4 peripheral banks (PB1..PB4). Each LEDC channel feeds the two sub-groups of one bank, so each bank produces a flickering light signal with fully controllable frequency, duty cycle, brightness, and phase.
- **Oscillator 5** drives the central group (CG) on its own LEDC channel. It uses the same oscillator mechanism but is typically configured at a very low frequency (or 0 Hz) for smooth ambient brightness or breathing effects.

The mapping between oscillators and LEDC channels is fixed: oscillator *i* always writes to LEDC channel *i*. There is no dispatch table.

For each oscillator the **frequency**, **brightness**, and **duty cycle** are generated by independent modulators (static, linear, or LFO). The modulator outputs are combined with the oscillator waveform to produce the final LEDC duty cycle.

---

### LED Driver

After examining several LED drivers, the AL8860 was chosen as it perfectly suits the project's needs. The brightness of the connected LEDs is controlled with a PWM signal applied to the CTRL pin of the AL8860. The same AL8860 circuit is used for all 9 groups, all driven by PWM signals generated by the ESP32 LEDC peripheral.

The schematic for one LED group is as follows:

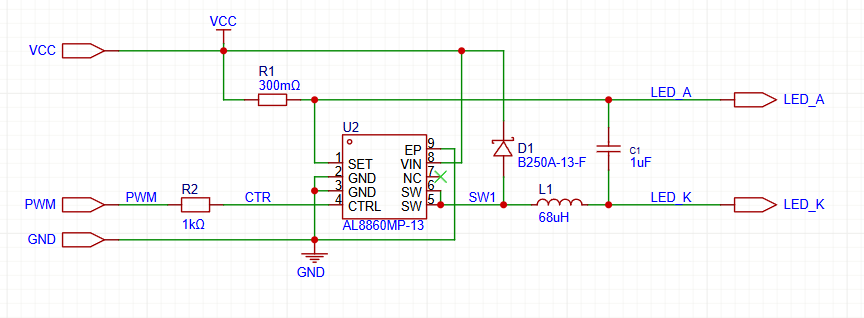
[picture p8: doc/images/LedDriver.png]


The AL8860 is a buck (step-down) constant-current LED driver. Its role is to regulate the current through the LEDs at a fixed value determined by the sense resistor R1. With R1 = 300 mΩ, the regulated LED current is:

$$I_{LED} = \frac{V_{SET}}{R_1} = \frac{0.1\,V}{0.300\,\Omega} \approx 333\,mA$$

The 4 LEDs in each group are connected in series, giving a total forward voltage of approximately 13.6 V (4 x 3.4 V). The driver circuit is powered by a 24 V supply, which provides a comfortable margin.

The CTRL pin of the AL8860 operates in digital mode:

- **CTRL > 2.5 V**: driver active, regulated current flows through LEDs
- **CTRL < 0.4 V**: driver shut down, LED off

This makes the CTRL pin ideal for direct connection to a PWM signal generated by the ESP32, through a 1 kΩ series resistor (R2) for protection.

**PWM dimming.** A digital PWM signal applied to the CTRL pin produces an average LED current proportional to its duty cycle. The datasheet recommends a PWM frequency **below 500 Hz** for best resolution and accuracy (better than 1% from 1% to 100% duty at 500 Hz); higher PWM frequencies reduce dimming dynamic range and accuracy. The 1 kHz LEDC carrier chosen for this project is therefore a practical compromise: it is high enough to be invisible, while still maintaining acceptable accuracy for the visible brightness range.

> Note: In the prototype we will use PicoBuck LED driver modules from SparkFun. They use the AL8805 LED driver instead of the AL8860, but the two drivers are functionally equivalent even though the AL8860 is recommended for new designs.

---

### LED Control: Oscillators and LEDC Channels

All LED groups are driven by the same two-level PWM architecture: a software oscillator produces a low-frequency waveform, and an ESP32 LEDC hardware channel generates the high-frequency carrier. The oscillator value sets the instantaneous duty cycle of the carrier, giving independent control of flicker frequency, duty cycle, brightness, and phase.

Led Control

#### Fixed Oscillator-to-Channel Mapping

The mapping between oscillators, LEDC channels, and LED groups is fixed. There is no dispatch table.

|Oscillator|LEDC channel|LED group|Typical use|
|---|---|---|---|
|1|0|PB1 (2 sub-groups)|FLS flicker|
|2|1|PB2 (2 sub-groups)|FLS flicker|
|3|2|PB3 (2 sub-groups)|FLS flicker|
|4|3|PB4 (2 sub-groups)|FLS flicker|
|5|4|CG (central)|Ambient / breathing|

Oscillators 1-4 drive the four outer banks and are normally used in the 1-100 Hz flicker range. Oscillator 5 drives the central group; it uses the same mechanism but is typically run at 0 Hz (fixed brightness) or at a very low frequency (e.g. 0.1-0.5 Hz) for a smooth breathing effect.

#### Two-Level PWM Modulation

The oscillator parameters are: **waveform** and **phase** (0-360 degrees). The **frequency**, **brightness**, and **duty cycle** are produced by independent modulators (static, linear, or LFO) and passed to the oscillator and LEDC path.

Since the signal driving the AL8860 CTRL pin must be a digital PWM signal, a two-level **PWM modulation** technique is used to independently control both brightness and the visible flicker frequency and duty cycle:

- **Carrier signal**: High-frequency PWM (1 kHz), generated by the ESP32 LEDC hardware peripheral, controls the LED brightness via its duty cycle.
- **Modulating signal**: Low-frequency waveform (0-100 Hz), generated in ESP32 software, creates the visible flashing effect. Its frequency and duty cycle determine the flicker parameters. At 0 Hz, the oscillator must output a constant value of `1.0`, independently of waveform and phase, so the brightness parameter directly sets a fixed output.

The two levels are combined as follows:

```text
final_duty = osc_value(t) * brightness
ledcWrite(channel, final_duty)
```

When `osc_value` is at its peak, the LEDC runs at full brightness duty cycle. When `osc_value` is zero, the LEDC output is zero and the LED is off. This gives fully independent control of all three parameters.



#### Brightness Control: ESP32 LEDC Peripheral

The ESP32-S3 LEDC peripheral provides 8 hardware PWM channels; 5 are used in this design. Each LEDC channel is initialized at a fixed carrier frequency (1 kHz) with 10-bit resolution (0-1023 duty range).

Brightness is set by calling `ledcWrite(channel, duty)` where `duty` is proportional to the desired brightness level. Since the carrier frequency (1 kHz) is well above the flicker range and above the threshold of visual persistence, it is invisible to the eye: only the average brightness is perceived.

#### Frequency Generator: ESP32 Software Oscillator

The low-frequency modulating signal is generated entirely in ESP32 software using a high-precision hardware timer (`esp_timer`), which provides microsecond-level accuracy independent of the FreeRTOS task scheduler.

**Waveform shapes supported:**

All waveforms are normalized to the range 0.0-1.0. Each waveform has a **frequency** and a **duty cycle** parameter. The meaning of duty cycle depends on the waveform type:

|Waveform|Duty Cycle Meaning|Generation|FLS Effect|
|---|---|---|---|
|Square|Fraction of period at HIGH level (classic PWM)|Computed directly from phase and duty|Sharp, stroboscopic pulses|
|Triangle|Fraction of period in ascending phase (0% or 100% gives a sawtooth variant)|Computed directly from phase and duty|Linear fade in/out, asymmetry controllable|
|Sine|Not applicable (fixed shape)|64-sample LUT|Gentle, organic stimulation|
|Custom|Encoded in the LUT (user-defined shape)|User-supplied LUT|Any specific FLS therapeutic profile|

Note: sawtooth is not a separate waveform type. It is a degenerate case of the triangle waveform obtained by setting duty cycle to 0% (instant rise then full fall ramp) or 100% (full rise ramp then instant fall).

**Implementation: DDS Phase Accumulator with LUT or Direct Generation**

A **Direct Digital Synthesis (DDS)** phase accumulator runs in the 1 kHz timer callback. At each tick the phase advances by an amount proportional to the current frequency; the phase is then converted to a waveform value.

- **Sine** and **custom** use a 64-sample LUT. The sine LUT is pre-computed at step startup to avoid trigonometric calls in the timer callback. The custom LUT is supplied by the user. Changing waveform or phase rebuilds or reloads the LUT; duty cycle does not affect LUT-based waveforms.
- **Square** and **triangle** are computed directly from the phase accumulator and the duty cycle parameter each tick. They do not use a LUT, so they do not suffer from LUT under-sampling at higher frequencies. Because they are computed directly, the duty cycle can be modulated in real time without a LUT rebuild.

```c
// Timer callback - runs at 1 kHz
void osc_callback(void* arg) {
    for (int i = 0; i < NUM_OSC; i++) {
        // Advance DDS phase
        osc_phase[i] += (LUT_SIZE * current_freq[i]) / CALLBACK_RATE_HZ;
        if (osc_phase[i] >= LUT_SIZE) osc_phase[i] -= LUT_SIZE;

        if (oscillator_uses_lut(i)) {
            osc_value[i] = lut[i][(int)osc_phase[i]];
        } else {
            osc_value[i] = compute_waveform(osc_waveform[i], osc_phase[i], osc_duty[i]);
        }
    }

    // Write each oscillator directly to its fixed LEDC channel
    for (int ch = 0; ch < 5; ch++) {
        ledcWrite(ch, (int)(osc_value[ch] * current_brightness[ch] * MAX_DUTY));
    }
}
```

This approach ensures:

- Frequency changes are **instantaneous and glitch-free** for all 5 oscillators
- Sine is fast (one LUT lookup) and accurate at all supported frequencies
- Square and triangle are always generated with full tick-level timing resolution
- Custom therapeutic waveform profiles can be loaded as arbitrary LUTs

**Parameter update constraints:**

|Parameter|Dynamic during step?|Mechanism|
|---|---|---|
|Frequency|Yes|DDS phase increment updated each parameter tick|
|Brightness|Yes|Multiplied at callback time, no LUT rebuild|
|Duty cycle|Yes|Passed to the oscillator each tick; affects only square and triangle, with no LUT rebuild|
|Phase|Set once at step start|Initializes the phase accumulator|

Duty cycle can be changed at any time because square and triangle waveforms are computed directly from the phase accumulator and duty value each tick. For sine and custom LUT waveforms, the duty-cycle modulator output has no effect on the generated sample.

The **phase** parameter is useful when multiple oscillators are used, as it allows you to adjust the relative positions of the waveforms.

**Note on timing constraints:** The LEDC peripheral applies a new duty cycle at the start of each carrier period. At a 1 kHz carrier, updates more frequent than every 1 ms provide no additional benefit.

With the 64-sample LUT used for sine and custom, the phase increment per tick reaches one sample per tick at 1000 / 64 ≈ 15.6 Hz. Above this frequency the oscillator still produces the correct fundamental period, but the LUT is under-sampled: not every sample is output, so waveform edges and harmonics become coarser. For example at 40 Hz with a 64-sample LUT, only 25 of the 64 samples are used each period. To keep full sine fidelity above ~15 Hz, reduce the LUT size (e.g., 32 or 16 samples) so that the phase increment per tick stays close to one sample.

Square and triangle are generated directly from the phase accumulator each tick and are therefore not affected by LUT under-sampling. Their timing accuracy is limited only by the 1 ms LEDC update rate.

---

## Bluetooth Communication

The device is controlled over a Bluetooth Low Energy (BLE) connection. The transport uses a command/response protocol over a single write characteristic and a status notification characteristic. All message formats, service UUIDs, fragmentation rules, and error codes are detailed in [BLE Transport Protocol](ble_protocol.md).

The main high-level commands supported by the firmware are:

- **Load full sequence** — transfers a complete compact sequence to the device and loads it as the active sequence.
- **Update step** — transfers a single step and updates the corresponding step in the currently loaded sequence.
- **Play** — starts or resumes sequence playback.
- **Pause** — freezes the current playback state.
- **Stop** — stops playback and resets to the beginning.
- **Seek** — jumps to an absolute position in the sequence, in milliseconds.

The following sections describe the data produced by these commands. The precise binary command format is documented in [BLE Transport Protocol](ble_protocol.md).

## Sequence Description

### Overview

In normal mode of operation, the device is controlled by playing **sequences** composed of ordered **steps**. Each step has a fixed duration and defines the waveform parameters for each of the 5 oscillators. Oscillators 1-4 drive banks PB1-PB4 and oscillator 5 drives the central group. Steps are played back one after another, with optional looping, pause, and seek capabilities.

### Step Definition

A step has one global parameter and a set of per-oscillator parameters for oscillators 1 to 5. Oscillators 1-4 drive the outer banks PB1-PB4; oscillator 5 drives the central group CG:

**Global parameter:**

|Parameter|Description|
|---|---|
|`duration`|Duration of the step in seconds, common to all oscillators|

**Per-oscillator parameters (repeated for oscillators 1 to 5):**

|Parameter|Description|
|---|---|
|`waveform`|Oscillator waveform shape: sine, square, triangle, or custom|
|`duty`|Duty cycle modulator: `static(%)`, `linear(start_%, end_%)`, or `lfo(waveform, freq_hz, low_%, high_%)` (no LUT rebuild)|
|`phase`|Starting position in the oscillator LUT at the beginning of this step (0-360 degrees)|
|`freq`|Frequency modulator: `static(hz)`, `linear(start_hz, end_hz)`, or `lfo(waveform, freq_hz, low_hz, high_hz)`|
|`brightness`|Brightness modulator: `static(%)`, `linear(start_%, end_%)`, or `lfo(waveform, freq_hz, low_%, high_%)`|

### Parameter Control Modes

Each oscillator has three modulated parameters, `freq`, `brightness`, and `duty`. Each can independently use one of three control modes: `static`, `linear`, or `lfo`.

#### Static Mode

The parameter stays at a fixed value for the duration of the step.

```text
Example step - oscillator 1 (drives PB1):
  duration:   20 s
  waveform:   square
  duty:       50%
  phase:      0 degrees
  freq:       static 10 Hz
  brightness: static 80%

Example step - oscillator 5 (drives CG):
  duration:   20 s
  waveform:   sine
  duty:       50%
  phase:      0 degrees
  freq:       static 0 Hz
  brightness: static 40%
```

#### Linear Mode

The parameter interpolates smoothly and linearly from the start_value at the start of the ramp to the end_value over the step duration.

```text
Example step - oscillator 1 (drives PB1):
  duration:   20 s
  waveform:   triangle
  duty:       linear 25% - 75%
  phase:      0 degrees
  freq:       linear 10 - 12 Hz
  brightness: linear 50% - 80%
```

At each parameter update tick, the current value is:

```text
current_value = start + (end - start) * (elapsed / duration)
```

#### LFO Mode (Low Frequency Oscillator Modulation)

A simple **Low Frequency Oscillator (LFO)** modulates the parameter rhythmically between a low and a high value. The LFO has no LUT and supports sine (or a triangle approximation) and square with a fixed 50% duty cycle.

```text
Example step - oscillator 2 (drives PB2):
  duration:   10 s
  waveform:   square
  duty:       lfo square 0.5 Hz  10% - 90%
  phase:      90 degrees
  freq:       lfo sine   2 Hz  10 Hz - 20 Hz
  brightness: lfo square 0.5 Hz  60% - 90%

Example step - oscillator 5 (drives CG):
  duration:   10 s
  waveform:   sine
  duty:       50%
  phase:      0 degrees
  freq:       lfo sine 0.2 Hz  (breathing)
  brightness: lfo sine 0.2 Hz  30% - 50%
```

At each parameter update tick, the LFO value is evaluated and mapped to the parameter range:

```text
lfo_value     = evaluate_lfo(lfo_waveform, lfo_freq, t)   // 0.0 to 1.0
current_value = low + (high - low) * lfo_value
```

**Frequency Modulation and its FLS effect:**

When the LFO is applied to the frequency parameter, the result is a **frequency-modulated (FM) flicker signal**: the visible flicker rate itself oscillates rhythmically between two values. This produces a rich, continuously varying stimulation that differs markedly from a fixed-frequency flash. The perceived effect is a "breathing" or "pulsating" quality to the light, and the range and speed of frequency modulation give precise control over the intensity of this effect. Narrow LFO ranges (e.g., 10-12 Hz) produce subtle vibrato-like variation; wide ranges (e.g., 5-30 Hz) produce dramatic sweeping effects that cross multiple brainwave frequency bands within a single step.

### Sequence Architecture

The full signal flow from the sequence engine down to all LED groups is:

```mermaid
flowchart LR
    subgraph Control sources
        ED([Editor])
        PL([Player])
    end

    ED -->|realtime parameters| CTRL
    PL -->|step parameters| CTRL

    subgraph CTRL[led_engine per oscillator]
        direction TB
        FM[frequency_modulator<br/>static / linear / lfo]
        BM[brightness_modulator<br/>static / linear / lfo]
        DM[duty_cycle_modulator<br/>static / linear / lfo]
        OSC[oscillator<br/>waveform, phase]
    end

    FM -- frequency_hz --> OSC
    DM -- duty_cycle --> OSC
    OSC -- osc_value --> LED
    BM -- brightness --> LED

    subgraph LED[led_control]
        direction TB
        PWM[LEDC PWM 1 kHz]
        DRV[AL8860 driver]
    end

    LED -->|PWM| LEDS[LED banks PB1..PB4 / CG]
```

### Timing Layers Summary

|Layer|Update Rate|Responsibility|
|-----|---|---|
|Sequencer|100 ms|Advance to next step, apply static oscillator settings|
|led_engine|1 ms|Evaluate modulators, call `oscillator_tick()`, write `led_control`|
|LEDC peripheral|Every 1 ms (carrier period)|Output PWM to AL8860 banks PB1..PB4 and central group CG|

## Mode of Operation

The device can be used in two distinct operating modes: **Sequence Mode** and **Realtime Mode**. Both modes use the same Bluetooth transport and the same underlying oscillator/modulator engine, but they differ in how parameters are supplied and how playback is controlled.

### Sequence Mode

In Sequence Mode the device plays a pre-loaded sequence of steps. Each step has a fixed duration and the sequencer advances automatically unless a control command changes the state.

#### Bluetooth Commands in Sequence Mode

The high-level commands used in Sequence Mode are summarized below. The complete binary message format, fragmentation rules, and error codes are documented in [BLE Transport Protocol](ble_protocol.md).

| Command | Description |
| --- | --- |
| `loadSequence` | Loads a complete sequence into device memory. The host transfers the compact sequence in chunks; the firmware validates it and replaces the active sequence. |
| `updateStep` | Updates a single step in the currently loaded sequence. The host transfers the new step data; the firmware validates it and replaces the step in the active sequence. If the updated step is the currently playing step, the change is applied immediately. |
| `play` | Starts or resumes playback from the current position. |
| `pause` | Freezes playback on the current step. |
| `stop` | Stops playback and returns to the beginning of the sequence. |
| `seek` | Jumps to an absolute position in the sequence, expressed in milliseconds. |

#### Playback State Machine

The firmware maintains a simple three-state playback machine: `Stop`, `Play`, and `Pause`.

- **Stop state.** No playback is active. The LED output is off and the sequencer cursor is positioned at the beginning of the sequence (or at the last `seek` position if one was issued). `loadSequence` and `updateStep` can be used to modify the loaded sequence. A `play` command transitions to the `Play` state; a `seek` command updates the cursor without producing light.

- **Play state.** The sequencer advances through steps according to their durations. At each step start the oscillator phase, modulator start values, and static parameters are applied; linear ramps and LFO modulators evolve over time. When the last step finishes, the sequence ends and the firmware automatically transitions back to the `Stop` state.

- **Pause state.** Playback is suspended on the current step. Static and linear modulator values are frozen at the values they had when the pause occurred, and the oscillator phase is held. LFO modulators continue to run, so any parameters controlled by an LFO keep breathing. This lets the user preview the current step while retaining its modulation character. `play` resumes from the paused position; `stop` resets to the beginning; `seek` jumps to a new position while remaining paused.

#### Seek Behavior

A `seek` can be issued in any of the three states. The result depends on the active state:

- **Seek in Stop.** The target position is set as the starting point for the next `play`. The LED output remains off; only the internal cursor is updated.

- **Seek in Play.** The sequencer jumps to the step containing the requested position, applies that step's static and start parameters, and resumes playing from the new position.

- **Seek in Pause.** The sequencer jumps to the requested position, evaluates the step's parameters at the new time, and pauses there. Static and linear values are frozen at the new position and LFOs continue from that point.

### Realtime Mode

Realtime Mode is entered by loading a sequence that contains a single step with `duration = 0`. It is intended for live control of the light output without any automatic time progression.

Only two states exist in this mode: `Stop` and an active frozen state called `Hold` (the active state is not a true "play" state, because nothing advances with time).

- **Stop state.** The LED output is off. A `play` command transitions the device to the `Hold` state using the current step's parameters.

- **Hold state.** The timeline is frozen, but the LED engine remains active. Linear modulators are treated as if they were static: only their `start` value is used because no elapsed time exists. LFOs continue to run, so any parameters controlled by an LFO keep breathing. Static values and oscillator phase are held until a new step arrives.

Note that in this operating mode, since time does not change, a linear modulator behaves like a static modulator and uses only the initial value.

Parameters are updated by sending an `updateStep` command with a new single-step sequence. The firmware validates and applies the new step immediately, replacing the current live parameters while remaining in the `Hold` state. This allows live editing of frequency, brightness, duty, phase, waveform, or modulator configuration without stopping the light.

A `stop` command returns the device to the `Stop` state and turns the LEDs off. Since there is no timeline, `seek` and `pause` are not applicable in Realtime Mode.

## Hardware Prototype

The prototype construction details are documented in [HardwarePrototype.md](HardwarePrototype.md).

## Software Prototype

The software architecture and firmware design are documented in [SoftwareArchitecture.md](SoftwareArchitecture.md).

## Useful References

- [10pcs 1W 3W 5W high power red/yellow/blue/green/white/warm white/cool white/UV/full spectrum LED emission lamp + 20mm Star PCB - AliExpress](https://fr.aliexpress.com/item/4001113713002.html)
- [10pcs 1W 3W High Power warm white/cool white /natural white/red/green/Blue/Royal blue IR LED with 20mm star pcb - AliExpress](https://fr.aliexpress.com/item/1005003381591196.html)
- [25pcs/100pcs 1W 3W High Power LED Diodes Warm Cold White/Natural White/Red/Green/Blue/Royal Blue With 20mm White Black PCB - AliExpress](https://fr.aliexpress.com/item/1005002960208410.html)
- [AL8860: 40V 1.5A STEP DOWN LED DRIVER WITH INTERNAL SWITCH (AL8860)](https://www.diodes.com/part/view/AL8860)
- [ESP32 PWM Fan Controller \| DroneBot Workshop](https://dronebotworkshop.com/esp32-pwm-fan/)
- [Unit 8Encoder](https://docs.m5stack.com/en/unit/8Encoder)
- [wagiminator/ATtiny412-I2C-Rotary-Encoder: Rotary Encoder with I²C Interface](https://github.com/wagiminator/ATtiny412-I2C-Rotary-Encoder)
- [MIDI Mix \| Akai Professional](https://www.akaipro.com/midimix/)
- [Alimentation 24V 5A 120W](https://www.amazon.fr/Alimentation-Adaptateur-Transformateur-Convertisseur-Surveillance/dp/B0FWRG2X67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)
- [5A DC-DC Step Down Power Supply Buck Module Converter Voltage Regulator 3.3V 5V 6V 9V 12V 18V 24V](https://fr.aliexpress.com/item/1005005921557535.html)
- Spacer washers
- [Using Temperature-Sensing Diodes with Remote Thermal Sensors](https://ww1.microchip.com/downloads/en/AppNotes/000001839A.pdf)
- [EMC2101 Fan Controller](https://learn.adafruit.com/emc2101-fan-controller-and-temperature-sensor) [2N3904](https://fr.aliexpress.com/item/1005003384179636.html)
- [TMP35/TMP36/TMP37 (Rev. H) Datasheet](https://www.analog.com/media/en/technical-documentation/data-sheets/TMP35_36_37.pdf)  - [TMP36GT9Z TO92](https://fr.aliexpress.com/item/1005009466938545.html)

## SparkFun References

- [PicoBuck LED Driver - SparkFun Electronics](https://www.sparkfun.com/picobuck-led-driver.html)
- [FemtoBuck LED Driver - SparkFun Electronics](https://www.sparkfun.com/femtobuck-led-driver.html)
- [FemtoBuck: 6-36V 350mA constant-current LED driver - github](https://github.com/sparkfun/FemtoBuck)
- [SparkFun Qwiic OLED - (1.3in., 128x64) - SparkFun Electronics](https://www.sparkfun.com/sparkfun-qwiic-oled-1-3in-128x64.html)
- [SparkFun Qwiic OLED Display (1.5 in., 128x128) - SparkFun Electronics](https://www.sparkfun.com/sparkfun-qwiic-oled-display-1-5-in-128x128.html)
- [GitHub PicoBuck: Three-channel current driver for LEDs](https://github.com/sparkfun/PicoBuck)
- [Prototyping with I²C has never been easier.](https://www.sparkfun.com/qwiic)

## Adafruit References

- [Learn Adafruit I2C Quad Rotary Encoder Breakout](https://learn.adafruit.com/adafruit-i2c-quad-rotary-encoder-breakout)
- [Learn Adafruit I2C QT Rotary Encoder](https://learn.adafruit.com/adafruit-i2c-qt-rotary-encoder/overview)
- [Adafruit I2C Stemma QT Rotary Encoder Breakout with NeoPixel](https://www.adafruit.com/product/4991)
- [Adafruit I2C Stemma QT Rotary Encoder Breakout with Encoder](https://www.adafruit.com/product/5880)
- [Adafruit I2C Quad Rotary Encoder Breakout with NeoPixel](https://www.adafruit.com/product/5752)
- [Black Nylon Machine Screw and Stand-off Set – M2.5 Thread](https://www.adafruit.com/product/3299)
- [Adafruit Swirly Aluminum Mounting Grid for 0.1 Spaced PCBs](https://www.adafruit.com/product/5781)
- [STEMMA QT / Qwiic JST SH 4-pin Cable with Premium Female Sockets - 150mm Long](https://www.adafruit.com/product/4397)
- [Adafruit Mini I2C Gamepad with seesaw](https://www.adafruit.com/product/5743)
- [Adafruit EMC2101 I2C PC Fan Controller and Temperature Sensor](https://www.adafruit.com/product/4808)
- [JST PH 2mm 4-pin Vertical Connector (10-pack)](https://www.adafruit.com/product/4390)
- [2-Axis Joystick : Adafruit Industries, Unique & fun DIY electronics and kits](https://www.adafruit.com/product/245)
- [Analog 2-axis Thumb Joystick with Select Button + Breakout Board](https://www.adafruit.com/product/512)
- [Monochrome 0.96 128x64 OLED Graphic Display](https://www.adafruit.com/product/326)
- [Adafruit Monochrome 1.12 128x128 OLED Graphic Display](https://www.adafruit.com/product/5297)

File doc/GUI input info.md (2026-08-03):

# MPHEditor Step Editor GUI Specification

## Target Platform

Windows first. Tablet may be supported later. Phone is out of scope.

## Rotary Button Behavior

A rotary button behaves like a volume knob:

- Click and drag up or right to rotate clockwise (increase).
- Click and drag down or left to rotate counterclockwise (decrease).
- The current value or selected label is shown in the center.
- Numeric knobs support direct value entry: click the center, type, confirm with Enter, cancel with Escape.
- Keyboard modifiers:
  - **Shift** : coarse step (e.g. +10).
  - **Alt** : fine step (e.g. +0.1).

Numeric values are displayed **below** the rotary button.

## Parameter Ranges

| Parameter | Range | Notes |
|---|---|---|
| Frequency | 0.0 – 100.0 Hz | 0 Hz is valid and produces static output  |
| Brightness | 0.0 – 100.0 %  | Mapped to 0.0 – 1.0 for the firmware |
| Duty cycle | 0.0 – 100.0 %  | Mapped to 0.0 – 1.0 for the firmware |
| Phase | 0 – 360 deg | |
| LFO frequency | 0.1 – 10.0 Hz  | |

## Modulator Modes

Modes use short labels: **FIX**, **LIN**, **LFO**.

- **FIX** (static): one rotary button for the fixed value.
- **LIN** (linear): two rotary buttons for start and end values.
- **LFO** : one rotary selector for waveform (sine/square), plus three rotary buttons for LFO frequency, low value, and high value.

When the mode changes, the controls inside the modulator update automatically. Values from the previous mode may be reused where it makes sense (e.g. the current value becomes the FIX value or the LIN start value).

## Oscillator Display

Each oscillator shows, from left to right:

1. **Waveform selector** rotary button.
2. **Phase** rotary button.
3. **Frequency** modulator display.
4. **Brightness** modulator display.
5. **Duty cycle** modulator display.

## Step Display

A step is visualized with 5 oscillator panels stacked vertically.

The step duration is **not** edited here; it is set in the sequence timeline view where the current step position and duration are already shown.

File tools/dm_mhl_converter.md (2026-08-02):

# Dream Machine to Morpheus HypnoLight converter

This document describes a Python script that converts Dream Machine sequences into the Morpheus HypnoLight (MHL) format.

## Overview

Two conversion modes are required:

1. **Single-sequence mode** – convert one `sequence.json` file.
2. **Batch mode** – convert an entire Dream Machine `Programmes` tree, including every collection and the sequences it contains.

For each converted sequence directory:

- The output file is written as `sequence.json` in the same directory (Morpheus HypnoLight format, immediately usable).
- If a `son.mp3` audio file is present, it is renamed to `sound.mp3`.

## Field conversion

### Sequence metadata

- **Convert:** `version`, `author`, `createdAt`, `name`
- **Ignore:** `duration`, `gradient`

### Steps

- **Convert:** `duration` = `timeEnd - timeStart`
- **Ignore:** `index`, `runtimeType`

### Oscillators (1 to 5)

For each of the 4 Dream Machine oscillators:

| MHL field | Mode | Start value | End value |
|---|---|---|---|
| `frequency` | `linear` | `min(frequencyStart, 100)` | `min(frequencyEnd, 100)` |
| `brightness` | `linear` | `brightnessStart * Bcoef / 100` | `brightnessEnd * Bcoef / 100` |
| `duty` | `linear` | `dutyStart / 100` | `dutyEnd / 100` |
| `waveform` | `square` | — | — |

- `runtimeType` is ignored.
- A missing oscillator, or an oscillator with no LEDs, becomes an oscillator with `brightness` mode = `static` and value = `0`.
- Oscillator 5 is always converted to `brightness` mode = `static`, value = `0`.

## Brightness correction (Bcoef)

In the Dream Machine, each LED has its own brightness factor. The correction coefficient is the average of the factors for the LEDs used in the step.

LED factors:

- `A1` = 1
- `A2`-`A3` = 4
- `A4`–`A5` = 2
- `B1`–`B4` = 3

Formula:

```text
Bcoef = sum of the LED factors used in the step / 21
```

Example:

```text
LEDs = ["A1", "A4", "B3"]
Bcoef = (1 + 2 + 3) / 21 = 0.2857...
brightnessStart = 50 => start = 50 * 0.2857 / 100 = 0.14285 => 0.143
```

## File name and location

### Single-sequence conversion

The script takes a Dream Machine `sequence.json` file as input and:

1. Renames the original Dream Machine file to `sequence.dm` (preserving the source data).
2. Writes the converted Morpheus HypnoLight data as `sequence.json` in the same directory.
3. If a `son.mp3` audio file is present, copies it to `sound.mp3` (the original `son.mp3` is kept so the source remains intact).

### Batch conversion (`Programmes` tree)

The script takes a Dream Machine `Programmes` directory as input and recursively converts every `sequence.json` file found in the tree using the single-sequence conversion rules:

- Rename the original `sequence.json` to `sequence.dm`.
- Write the converted file as `sequence.json`.
- Copy `son.mp3` to `sound.mp3` if it exists.

Files that are not in Dream Machine format (e.g., already converted MHL files) are skipped.

## Spread mode (`--spread`)

Dream Machine sequences often describe a single oscillator driving several LED groups, while Morpheus HypnoLight maps one oscillator to one LED group. The optional `--spread` flag addresses this by replicating the active oscillator across the first four MHL oscillators when a Dream Machine step contains exactly one active oscillator.

An oscillator is considered **active** when its `led` list is non-empty. Dream Machine files frequently declare all four oscillator slots, leaving the unused ones with an empty `led` array; those empty slots are ignored for the spread decision.

- Frequency, brightness, and duty modulators are copied unchanged.
- The replicated oscillators are phase-shifted by 90°: slot 0 at 0°, slot 1 at 90°, slot 2 at 180°, and slot 3 at 270°.
- If a step contains zero, two, three, or four active Dream Machine oscillators, the normal mapping is used.

Because spreading one oscillator across four LED groups can make those steps much brighter than steps with multiple active oscillators, you can adjust the replicated brightness with `--spread-scale FACTOR`.

- `--spread-scale 1.0` keeps the original brightness on each of the four oscillators (default).
- `--spread-scale 0.5` halves the brightness on each replicated oscillator.
- `--spread-scale 0.25` divides the brightness by 4 on each replicated oscillator.

Example:

```bash
python dm_to_mhl_converter.py --spread path/to/sequence.json
python dm_to_mhl_converter.py --spread --spread-scale 0.5 path/to/Programmes
```

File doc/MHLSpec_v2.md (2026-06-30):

# Morpheus HypnoLight Project

## Objective

The objective of this project is to create a device for visual and auditory stimulation. This type of device is often referred to as AVS (Audio-Visual Stimulation) or FLS (Flicker Light Stimulation). Flicker Light Stimulation is a non-invasive technique that uses rhythmic light variation to influence brain activity and the state of consciousness. It involves emitting rhythmic light pulses at specific frequencies, typically ranging from 3 Hz to 50 Hz. These light pulses stimulate the visual system, leading to a phenomenon called "visual entrainment," in which brain activity synchronizes with the frequency of the light. This synchronization can induce altered states of consciousness, like those experienced during deep meditation or under the influence of psychedelics, often accompanied by striking visual patterns and sensations beyond conscious control.

---

## Main Features

### Must have

- **Remote Sequence Mode of Operation**: The sequences to play are selected and controlled remotely from an application that communicates using BLE or Wi-Fi. This application can control multiple machines simultaneously.
- **Remote Real-time Mode of Operation**: Developers use this mode to control all machine parameters in real time without using sequences.
- Bluetooth Low Energy connectivity, used to connect to the control application and potentially to a sound system
- 8 outer LED groups (cold white), each driven by one of the 8 LEDC hardware channels, with the 4 oscillators dispatched to the groups via a routing table
- 1 central LED group (warm white) driven by a dedicated Sigma-Delta Modulator (SDM) channel with linear or LFO brightness control
- 4 oscillators with sine, triangle, square, and custom waveforms, each with controllable frequency, duty cycle, brightness, and phase
- Per-step oscillator-to-group assignment (each step can route oscillators to different LED groups)
- Low Frequency Oscillator (LFO) modulation of oscillator parameters, including frequency modulation for rich FLS effects
- Step-based sequence engine with linear interpolation or LFO modulation modes
- Capability to pause and seek loaded sequences
- Low-cost hardware (target: under $100)
- Low-noise cooling using a large PWM temperature controlled fan
- Compact and easy to carry with tripod mounting threads
- WiFi web server interface

### Could have

- **Local Sequence Mode of Operation**: Sequence selection and control is done locally, without the need for an external application. The sequences are stored locally on an SD card, and control is done using knobs, the touch screen, etc.
- **Local Real-Time Mode of Operation**: This mode allows developers to control all machine parameters in real time without using sequences. In Sequence mode, control is done using knobs, the touch screen, etc.
- Input devices: parameter controller (rotary knobs and switches), joystick, mouse, Touch screen
- Output devices: sound output direct through audio plug or remote via BLE
- Store sequences locally on SD card

---

## LED PCB

The LEDs are placed on a front panel PCB with an aluminum substrate for heat dissipation. In addition to the LEDs, the PCB contains temperature sensors that automatically activate the fan if the device overheats.

Numerous experiments have shown that the position of the LEDs on the PCB has no effect on the user's perception. For instance, a diode that lights up in the top left or bottom right corner of the board is perceived by the user in exactly the same way. Consequently, the LEDs have been arranged into nine groups of four LED as follows:

Led

The eight peripheral groups are connected to four oscillators, each of which has adjustable frequency, brightness, and duty cycle settings. They use cold white LEDs with a power rating of approximately one watt each (with a current of about 330 mA). Therefore, each group driven with a current of 330 mA can provide a maximum power output of 4.5 watts, for a total output of about 32 watts for all eight groups combined.

The central group uses four warm white LEDs rated at 3 W each but driven at about 2W (with a current of about 660 mA). Therefore, the central group can provide a maximum power output of 9 watts, 

---

## LED Control Architecture

### Overview

The device drives 9 LED groups using two distinct control paths:

- **Groups 1-8 (cold white, outer ring)**: driven by the 4 independent software oscillators via the 8 LEDC hardware channels of the ESP32-S3. Each group produces a flickering light signal with fully controllable frequency, duty cycle, brightness, and phase.

- **Group 9 (warm white, central)**: driven by a dedicated Sigma-Delta Modulator (SDM) hardware channel. It does not flicker; its brightness is controlled smoothly via linear interpolation or LFO modulation.

The 4 oscillators produce signal values that are dispatched to the 8 LEDC channels via a **dispatch table**, which is a step-level parameter: each step defines which oscillator drives which groups.

A given LED group can be driven by at most one oscillator at a time. Unassigned groups remain off for the duration of the step.

---

### LED Driver

After examining several LED drivers, the AL8860 was chosen as it perfectly suits the project's needs. With the AL8860, the brightness of the connected LEDs can be controlled either with an analog or a PWM signal.

Using the analog control input of the AL8860 has serious limitations:

- **Limited range**: only 0.5 V to 2.5 V
- **Potential nonlinearity**
- **Additional complexity** requiring D/A converters

Therefore, brightness is controlled by pulse width modulation (PWM) applied to the CTRL pin of the AL8860. The same AL8860 circuit is used for all 9 groups, including the central group; only the signal source differs.

The schematic for one LED group is as follows:



The AL8860 is a buck (step-down) constant-current LED driver. Its role is to regulate the current through the LEDs at a fixed value determined by the sense resistor R1. With R1 = 300 mΩ, the regulated LED current is:

$$I_{LED} = \frac{V_{SET}}{R_1} = \frac{0.1\,V}{0.300\,\Omega} \approx 333\,mA$$

The 4 LEDs in each group are connected in series, giving a total forward voltage of approximately 13.6 V (4 x 3.4 V). The driver circuit is powered by a 24 V supply, which provides a comfortable margin.

The CTRL pin of the AL8860 operates in digital mode:

- **CTRL > 2.5 V**: driver active, regulated current flows through LEDs
- **CTRL < 0.4 V**: driver shut down, LED off

This makes the CTRL pin ideal for direct connection to a PWM signal generated by the ESP32, through a 1 kΩ series resistor (R2) for protection.

> Note: In the prototype we will use PicoBuck LED driver modules from SparkFun. They use the AL8805 LED driver instead of the AL8860, but the two drivers are functionally equivalent even though the AL8860 is recommended for new designs.

---

### LED Control: Outer Groups (1-8)

Each group of LEDs is controlled by an oscillator, which allows the frequency, brightness and duty cycle parameters to be adjusted. The oscillator's output is connected to an LED driver that powers a group of four LEDs.

Led Control

#### Two-Level PWM Modulation

The oscillator parameters are: frequency (1-100 Hz), duty cycle (0-100%), brightness (0-100%), and phase (0-360 degrees).

Since the signal driving the AL8860 CTRL pin must be a digital PWM signal, a two-level **PWM modulation** technique is used to independently control both brightness and the visible flicker frequency and duty cycle:

- **Carrier signal**: High-frequency PWM (1 kHz), generated by the ESP32 LEDC hardware peripheral, controls the LED brightness via its duty cycle.
- **Modulating signal**: Low-frequency waveform (1-100 Hz), generated in ESP32 software, creates the visible flashing effect. Its frequency and duty cycle determine the flicker parameters.

The two levels are combined as follows:

```text
final_duty = osc_value(t) * brightness
ledcWrite(channel, final_duty)
```

When `osc_value` is at its peak, the LEDC runs at full brightness duty cycle. When `osc_value` is zero, the LEDC output is zero and the LED is off. This gives fully independent control of all three parameters.



#### Brightness Modulator: ESP32 LEDC Peripheral

The ESP32-S3 LEDC peripheral provides exactly 8 independent hardware PWM channels, one per outer LED group. Each channel is initialized at a fixed carrier frequency (1 kHz) with 10-bit resolution (0-1023 duty range).

Brightness is set by calling `ledcWrite(channel, duty)` where `duty` is proportional to the desired brightness level. Since the carrier frequency (1 kHz) is well above the flicker range and above the threshold of visual persistence, it is invisible to the eye: only the average brightness is perceived.

#### Frequency Generator: ESP32 Software Oscillator

The low-frequency modulating signal is generated entirely in ESP32 software using a high-precision hardware timer (`esp_timer`), which provides microsecond-level accuracy independent of the FreeRTOS task scheduler.

**Waveform shapes supported:**

All waveforms are normalized to the range 0.0-1.0. Each waveform has a **frequency** and a **duty cycle** parameter. The meaning of duty cycle depends on the waveform type:

| Waveform | Duty Cycle Meaning | FLS Effect |
| --- | --- | --- |
| Square | Fraction of period at HIGH level (classic PWM) | Sharp, stroboscopic pulses |
| Triangle | Fraction of period in ascending phase (0% or 100% gives a sawtooth variant) | Linear fade in/out, asymmetry controllable |
| Sine | Not applicable (fixed shape) | Gentle, organic stimulation |
| Custom | Encoded in the LUT (user-defined shape) | Any specific FLS therapeutic profile |

Note: sawtooth is not a separate waveform type. It is a degenerate case of the triangle waveform obtained by setting duty cycle to 0% (instant rise then full fall ramp) or 100% (full rise ramp then instant fall).

**Implementation: LUT + Phase Accumulator (DDS)**

Waveform shapes are pre-computed at step startup into a **Look-Up Table (LUT)** of N samples (e.g., N = 64). This avoids expensive floating-point trigonometric calculations inside the time-critical timer callback. The duty cycle parameter is applied during LUT generation, so changing the duty cycle triggers a LUT rebuild for that oscillator.

To handle continuously changing frequencies smoothly, a **Direct Digital Synthesis (DDS)** phase accumulator is used. Rather than stepping through the LUT at a fixed integer rate, a fractional phase value advances by an amount proportional to the current frequency on every timer tick:

```c
// Timer callback - runs at CALLBACK_RATE Hz (e.g. 1000 Hz)
void osc_callback(void* arg) {
    // 1. Compute all 4 oscillator values
    for (int i = 0; i < NUM_OSC; i++) {
        osc_phase[i] += (LUT_SIZE * current_freq[i]) / CALLBACK_RATE_HZ;
        if (osc_phase[i] >= LUT_SIZE) osc_phase[i] -= LUT_SIZE;
        osc_value[i] = lut[i][(int)osc_phase[i]];
    }

    // 2. Dispatch to LEDC channels (groups 1-8) via dispatch table
    for (int ch = 0; ch < 8; ch++) {
        int osc_id = dispatch_table[ch];
        if (osc_id < 0) { ledcWrite(ch, 0); continue; }  // unassigned -> off
        ledcWrite(ch, (int)(osc_value[osc_id] * current_brightness[osc_id] * MAX_DUTY));
    }
    // Group 9 (central) is handled independently by the SDM peripheral
}
```

This approach ensures:

- Frequency changes are **instantaneous and glitch-free** for all 4 oscillators
- Any waveform shape is supported by simply loading a different LUT
- The dispatch is a cheap integer lookup per channel per tick
- Custom therapeutic waveform profiles can be loaded as arbitrary LUTs

**Parameter update constraints:**

| Parameter | Dynamic during step? | Mechanism |
| --- | --- | --- |
| Frequency | Yes | DDS phase increment updated each parameter tick |
| Brightness | Yes | Multiplied at callback time, no LUT rebuild |
| Duty cycle | No (fixed per step) | LUT rebuilt once at step start |
| Phase | Set once at step start | Initializes the phase accumulator |
| Group assignment | Set once at step start | Updates the dispatch table |

Duty cycle is kept fixed per step because changing it requires rebuilding the LUT. For FLS purposes this is not a limitation: the perceptual difference between smoothly swept duty cycle and step-wise updated duty cycle is negligible.

The **phase** parameter is useful when multiple oscillators are used, as it allows you to adjust the relative positions of the waveforms.

**Note on timing constraints:** The LEDC peripheral applies a new duty cycle at the start of each carrier period. At a 1 kHz carrier, updates more frequent than every 1 ms provide no additional benefit. In practice, with a 64-sample LUT, the maximum meaningful flicker frequency is approximately 1000 / 64 = 15 Hz at full waveform resolution. At higher flicker frequencies, a smaller LUT (e.g., 32 or 16 samples) should be used to stay within this constraint.

---

### LED Control: Central Group (Group 9)

#### Role and Constraints

The central group uses warm white LEDs and acts as a background ambient light source. It does not flicker and is never driven by one of the 4 main oscillators. Its only controllable parameter is **brightness**, which can evolve smoothly over the duration of a step using either linear interpolation or LFO modulation.

#### Hardware: Sigma-Delta Modulator (SDM)

The ESP32-S3 Sigma-Delta Modulator (SDM) peripheral is used to drive the central group's AL8860 CTRL pin. The SDM generates a high-frequency 1-bit pulse-density stream (internal clock ~1 MHz) whose average density corresponds to the desired duty cycle. This gives:

- **Zero callback overhead**: the SDM hardware runs autonomously, no timer interrupt needed
- **8-bit resolution**: 256 brightness levels
- **Effective carrier ~78 kHz**: completely invisible, no risk of flicker artifact
- **Simple API**: a single function call sets the brightness

```c
// One-time setup
sdm_channel_handle_t sdm_chan;
sdm_config_t config = {
    .clk_src   = SDM_CLK_SRC_DEFAULT,
    .gpio_num  = CENTRAL_LED_GPIO,
    .sample_rate_hz = 1000000,
};
sdm_new_channel(&config, &sdm_chan);
sdm_channel_enable(sdm_chan);

// Update brightness from parameter layer (every 10-50 ms)
// density range: -128 (off) to +127 (full brightness)
int8_t density = (int8_t)(central_brightness * 255 - 128);
sdm_channel_set_pulse_density(sdm_chan, density);
```

#### Brightness Control Modes

The central brightness is updated by the **parameter layer** every 10-50 ms, independently of the oscillator callback. It supports the same two control modes as the main oscillators:

```c
// Parameter layer tick
if (central_mode == LINEAR) {
    central_brightness = start_b + (end_b - start_b) * (elapsed / duration);
}
else if (central_mode == LFO) {
    float lfo_val  = evaluate_lfo(lfo_form, lfo_freq, t);  // 0.0 to 1.0
    central_brightness = b_min + (b_max - b_min) * lfo_val;
}
sdm_channel_set_pulse_density(sdm_chan, brightness_to_density(central_brightness));
```

Example: a 5 Hz sine LFO between 30% and 50% brightness produces a gentle, slow breathing effect on the warm central light, updated at 100 Hz (every 10 ms = 20 samples per LFO period), giving a visually smooth curve.

---

## Sequence Mode of Operation

### Overview

In normal mode of operation, the device is controlled by playing **sequences** composed of ordered **steps**. Each step has a fixed duration and defines, for each of the 4 oscillators, both the waveform parameters and the oscillator-to-group routing, as well as the brightness of the central group. Steps are played back one after another, with optional looping, pause, and seek capabilities.

### Step Definition

A step has one global parameter, a set of per-oscillator parameters for groups 1-8, and a dedicated parameter block for the central group:

**Global parameter:**

| Parameter | Description |
| --- | --- |
| `duration` | Duration of the step in seconds, common to all oscillators |

**Per-oscillator parameters (repeated for oscillators 1 to 4), groups 1-8 only:**

| Parameter | Description |
| --- | --- |
| `groups` | List of LED groups (1-8) driven by this oscillator during this step |
| `waveform` | Waveform shape: sine, square, triangle, or custom |
| `duty` | Duty cycle: fixed value for the duration of the step (triggers LUT rebuild at step start) |
| `phase` | Starting position in the LUT at the beginning of this step (0-360 degrees) |
| `freq` | Frequency control: linear(start_hz, end_hz) or lfo(form, freq_hz, min_hz, max_hz) |
| `brightness` | Brightness control: linear(start_%, end_%) or lfo(form, freq_hz, min_%, max_%) |

**Central group parameters (group 9, always present):**

| Parameter | Description |
| --- | --- |
| `central_brightness` | Brightness control: linear(start_%, end_%) or lfo(form, freq_hz, min_%, max_%) |

### Parameter Control Modes

The two dynamic parameters for the oscillators (freq and brightness) and the central brightness can independently use one of two control modes during a step:

#### Linear Mode

The parameter interpolates smoothly and linearly from a start value to an end value over the duration of the step. Setting start and end to the same value keeps the parameter constant.

```text
Example step - oscillator 1:
  groups:     1, 5, 7
  duration:   20 s
  waveform:   sine
  duty:       50%
  phase:      0 degrees
  freq:       linear  10 Hz -> 12 Hz
  brightness: linear  80%   -> 50%

Central group:
  central_brightness: linear  40% -> 40%   (constant)
```

At each parameter update tick, the current value is:

```text
current_value = start + (end - start) * (elapsed / duration)
```

#### LFO Mode (Low Frequency Oscillator Modulation)

Inspired by classic analog synthesizers (e.g., Korg MS-20/MS-50), a dedicated **Low Frequency Oscillator (LFO)** modulates the parameter rhythmically between a minimum and maximum value at a given LFO frequency and waveform shape. This creates organic, evolving parameter motion within a step.

```text
Example step - oscillator 2:
  groups:     2, 4, 6
  duration:   10 s
  waveform:   sine
  duty:       50%
  phase:      90 degrees
  freq:       lfo  sine  2 Hz  10 Hz - 20 Hz
  brightness: lfo  triangle  0.5 Hz  60% - 90%

Central group:
  central_brightness: lfo  sine  5 Hz  30% - 50%
```

At each parameter update tick, the LFO value is evaluated and mapped to the parameter range:

```text
lfo_value     = evaluate_lfo(lfo_waveform, lfo_freq, t)   // 0.0 to 1.0
current_value = param_min + (param_max - param_min) * lfo_value
```

**Frequency Modulation and its FLS effect:**

When the LFO is applied to the frequency parameter, the result is a **frequency-modulated (FM) flicker signal**: the visible flicker rate itself oscillates rhythmically between two values. This produces a rich, continuously varying stimulation that differs markedly from a fixed-frequency flash. The perceived effect is a "breathing" or "pulsating" quality to the light, and the range and speed of frequency modulation give precise control over the intensity of this effect. Narrow LFO ranges (e.g., 10-12 Hz) produce subtle vibrato-like variation; wide ranges (e.g., 5-30 Hz) produce dramatic sweeping effects that cross multiple brainwave frequency bands within a single step.

### Sequence Architecture

The full signal flow from the sequence engine down to all LED groups is:

```mermaid
flowchart TD
    SEQ["**SEQUENCER**\nStep 1 -> Step 2 -> ..."]

    SEQ --> P1["**Param Layer - Osc 1**\nfreq / brightness\nlinear or LFO"]
    SEQ --> P2["**Param Layer - Osc 2**\nfreq / brightness\nlinear or LFO"]
    SEQ --> P3["**Param Layer - Osc 3**\nfreq / brightness\nlinear or LFO"]
    SEQ --> P4["**Param Layer - Osc 4**\nfreq / brightness\nlinear or LFO"]
    SEQ --> PC["**Param Layer - Central**\nbrightness only\nlinear or LFO"]

    P1 --> O1["**OSC 1**\nLUT + DDS\nphase accumulator"]
    P2 --> O2["**OSC 2**\nLUT + DDS\nphase accumulator"]
    P3 --> O3["**OSC 3**\nLUT + DDS\nphase accumulator"]
    P4 --> O4["**OSC 4**\nLUT + DDS\nphase accumulator"]
    PC --> SDM["**SDM peripheral**\n~1 MHz hardware\n8-bit resolution"]

    O1 --> DT["**DISPATCH TABLE**\nstep parameter\nch -> oscillator mapping"]
    O2 --> DT
    O3 --> DT
    O4 --> DT

    DT --> LEDC["**LEDC - 8 channels**\n1 kHz carrier / 10-bit\ngroups 1-8"]
    SDM --> AL9["**AL8860**\n333 mA - group 9"]

    LEDC --> AL18["**AL8860 x8**\n333 mA each\ngroups 1-8"]

    AL18 --> G18["**LED groups 1-8**\ncold white / flickering"]
    AL9  --> G9["**LED group 9**\nwarm white / ambient"]

    style SEQ      fill:#4A90D9,color:#fff,stroke:#2c6fad
    style DT       fill:#E8A838,color:#fff,stroke:#b07820
    style SDM      fill:#7B68EE,color:#fff,stroke:#5040cc
    style LEDC     fill:#7B68EE,color:#fff,stroke:#5040cc
    style AL18     fill:#5BAD6F,color:#fff,stroke:#3a8050
    style AL9      fill:#5BAD6F,color:#fff,stroke:#3a8050
    style G18      fill:#2E7D32,color:#fff,stroke:#1a5c1e
    style G9       fill:#E65100,color:#fff,stroke:#bf360c
```

### Timing Layers Summary

| Layer | Update Rate | Responsibility |
| ----- | --- | --- |
| Sequencer | Every few seconds | Advance to next step, rebuild LUTs, update dispatch table |
| Parameter layer | Every 10-50 ms | Linear interp or LFO update for all oscillators and central group |
| Phase accumulator | Every 1 ms (timer callback) | Drive all 4 oscillators, dispatch to 8 LEDC channels |
| LEDC peripheral | Every 1 ms (carrier period) | Output PWM to AL8860 channels 1-8 |
| SDM peripheral | Autonomous (~1 MHz) | Output pulse-density signal to AL8860 channel 9 |

## Real-Time Mode of Operation

In real-time mode, the notion of steps does not exist as it does in sequence mode. Therefore, the linear mode of the oscillator is replaced by a fixed-value mode.

### Parameter Control Modes

The two dynamic parameters for the oscillators (freq and brightness) and the central brightness can independently use one of two control modes:

#### Fixed Value Mode

The parameters stay constant.

```text
Example step - oscillator 1:
  groups:     1, 5, 7
  waveform:   sine
  duty:       50%
  phase:      0 degrees
  freq:       linear  10 Hz
  brightness: linear  80%

Central group:
  central_brightness: 40%
```

#### LFO Mode (Low Frequency Oscillator Modulation)

Works as described in the `Sequence mode`

```text
Example step - oscillator 2:
  groups:     2, 4, 6
  waveform:   sine
  duty:       50%
  phase:      90 degrees
  freq:       lfo  sine  2 Hz  10 Hz - 20 Hz
  brightness: lfo  triangle  0.5 Hz  60% - 90%

Central group:
  central_brightness: lfo  sine  5 Hz  30% - 50%
```

## Hardware Prototype

We will build a prototype to validate the hardware using the following main components

- Power Supply
- LEDs board
- Electronic board
- Experiment with a PWM Fan controlled by temperature sensors

### Power Supply

The prototype will be powered by  a [24V 5A 120W Power Supply with 5.5 x 2.5mm DC Output Jack](https://www.amazon.fr/Alimentation-Adaptateur-Transformateur-Convertisseur-Surveillance/dp/B0FWRG2X67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).

- This voltage will be used directly by the PicoBuck LED Buck Converters to power the LEDs
- A [5A DC-DC Step Down Power Supply Buck Converter](https://fr.aliexpress.com/item/1005005921557535.html) will be used to provide 5V power to the ESP32

### LEDs Board

- We will use 32 x [1W High Power cool white 6500K LED with 20mm star pcb](https://fr.aliexpress.com/item/1005003381591196.html) for the 8 peripheral groups
- We will use 4 x [3W High Power warm white LED with 20mm star pcb](https://fr.aliexpress.com/item/1005003381591196.html) for the central groups
- The Led will be placed on a [150x150 aluminum plate](https://www.amazon.fr/Plaque-aluminium-5083-150mm/dp/B07NYV688B/ref=sr_1_6?th=1) (or a [150x150x25mm Aluminum Heat Sink radiator for LED heat dissipation](https://fr.aliexpress.com/item/32958588818.html)) using [ARCTIC TP-4 : High Performance Thermal Pad 100x100x0,5 mm](https://www.amazon.fr/ARCTIC-TP-4-thermique-performance-irrégularités/dp/B0FZV47ZNR/ref=sxin_10_pa_sp_search_thematic_sspa?th=1)

### Electronic board

For the prototype the electronic will be placed on a Universal Double-Sided prototype PCB Board or on a breadboard.

The prototype uses three SparkFun PicoBuck LED drivers, each based on the AL8805 LED driver. The AL8805 is marked as "not recommended for new design" by its manufacturer, but it remains functionally equivalent to the AL8860 selected for the final product. The AL8860 is the recommended choice for the final PCB design.

The main components will be placed on a [90x150 Prototype board](https://www.amazon.fr/gp/product/B0FDQDNRJ2/ref=ox_sc_act_title_1?smid=A524J1LH0U8IN&th=1):

- An [ESP32-S3-DevKitC-1 8MB PSRAM 16MB FLASH N16R8 42Pin](https://fr.aliexpress.com/item/1005007173771226.html) development board using male and female 2.54mm pitch header connectors
Pinout
  
- 3 x [PicoBuck LED Driver](https://www.sparkfun.com/picobuck-led-driver.html) providing 9 outputs for the nine LED groups. Connection to the LEDs will be done using 12 x [3.5mm Screw Terminals](https://www.sparkfun.com/screw-terminals-3-5mm-pitch-2-pin.html) and connection to power supply will use a [DC Barrel Jack](https://www.sparkfun.com/dc-barrel-jack-adapter-female.html)
- One Qwiic connector connected to connect the following test devices using I2C protocol
  - 1-4 x [Adafruit I2C Quad rotary Encoder](https://learn.adafruit.com/adafruit-i2c-quad-rotary-encoder-breakout/arduino) used to test the oscillator behavior
  - 1 x [SparkFun Qwiic OLED Display 128x128](https://www.sparkfun.com/sparkfun-qwiic-oled-display-1-5-in-128x128.html)
- [DC-DC stepdown buck converter](https://fr.aliexpress.com/item/1005005921557535.html) to provide 5V to ESP32 Dev board

Simplified breadboard schematic



### Power Budget

The following table estimates the maximum power consumption of the prototype:

| Component | Power | Notes |
| --- | ----- | ----- |
| 8 peripheral LED groups | ~32 W | 4 × 1 W cold white LEDs per group |
| Central LED group | ~4.5 W | 4 × 3 W warm white LEDs at ~330 mA (default) |
| Central LED group (strap) | ~9 W | Same LEDs at ~660 mA with current-doubling strap |
| LED driver losses | ~4 W | ~10 % buck converter losses at full LED power |
| ESP32-S3 + peripherals | ~2.5 W | Dev board at 5 V, ~500 mA peak |
| 5 V buck converter | ~0.5 W | Conversion losses |
| PWM fan | ~1 W | 120 mm fan at moderate speed |
| **Total (default)** | **~44 W** | Corresponds to ~1.8 A at 24 V |
| **Total (central strap)** | **~49 W** | Corresponds to ~2.0 A at 24 V |

The 24 V / 5 A / 120 W supply leaves a comfortable margin (about 2.5× the expected maximum load), leaving room for additional peripherals, measurement errors, and supply aging.

### Thermal Considerations

At full brightness, the LEDs dissipate most of their consumed power as heat. The 150 × 150 mm aluminum plate (or optional heatsink) combined with the PWM fan must keep the LED temperature below the rated maximum. The temperature sensors on the LED PCB will increase the fan speed if the temperature exceeds a defined threshold. Exact thermal calculations will depend on the final plate thickness, heatsink choice, and ambient conditions, and will be validated during prototype testing.

## Software Prototype

TBD

## Enclosure Prototype

TBD

Use FreeCAD with MCP to drive 3D printer

## Useful References

- [10pcs 1W 3W 5W high power red/yellow/blue/green/white/warm white/cool white/UV/full spectrum LED emission lamp + 20mm Star PCB - AliExpress](https://fr.aliexpress.com/item/4001113713002.html)
- [10pcs 1W 3W High Power warm white/cool white /natural white/red/green/Blue/Royal blue IR LED with 20mm star pcb - AliExpress](https://fr.aliexpress.com/item/1005003381591196.html)
- [25pcs/100pcs 1W 3W High Power LED Diodes Warm Cold White/Natural White/Red/Green/Blue/Royal Blue With 20mm White Black PCB - AliExpress](https://fr.aliexpress.com/item/1005002960208410.html)
- [AL8860: 40V 1.5A STEP DOWN LED DRIVER WITH INTERNAL SWITCH (AL8860)](https://www.diodes.com/part/view/AL8860)
- [ESP32 PWM Fan Controller \| DroneBot Workshop](https://dronebotworkshop.com/esp32-pwm-fan/)
- [Unit 8Encoder](https://docs.m5stack.com/en/unit/8Encoder)
- [wagiminator/ATtiny412-I2C-Rotary-Encoder: Rotary Encoder with I²C Interface](https://github.com/wagiminator/ATtiny412-I2C-Rotary-Encoder)
- [MIDI Mix \| Akai Professional](https://www.akaipro.com/midimix/)
- [Alimentation 24V 5A 120W](https://www.amazon.fr/Alimentation-Adaptateur-Transformateur-Convertisseur-Surveillance/dp/B0FWRG2X67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)
- [5A DC-DC Step Down Power Supply Buck Module Converter Voltage Regulator 3.3V 5V 6V 9V 12V 18V 24V](https://fr.aliexpress.com/item/1005005921557535.html)
- Spacer washers
- [Using Temperature-Sensing Diodes with Remote Thermal Sensors](https://ww1.microchip.com/downloads/en/AppNotes/000001839A.pdf)
- [EMC2101 Fan Controller](https://learn.adafruit.com/emc2101-fan-controller-and-temperature-sensor) [2N3904](https://fr.aliexpress.com/item/1005003384179636.html)
- [TMP35/TMP36/TMP37 (Rev. H) Datasheet](https://www.analog.com/media/en/technical-documentation/data-sheets/TMP35_36_37.pdf)  - [TMP36GT9Z TO92](https://fr.aliexpress.com/item/1005009466938545.html)

## SparkFun References

- [PicoBuck LED Driver - SparkFun Electronics](https://www.sparkfun.com/picobuck-led-driver.html)
- [FemtoBuck LED Driver - SparkFun Electronics](https://www.sparkfun.com/femtobuck-led-driver.html)
- [FemtoBuck: 6-36V 350mA constant-current LED driver - github](https://github.com/sparkfun/FemtoBuck)
- [SparkFun Qwiic OLED - (1.3in., 128x64) - SparkFun Electronics](https://www.sparkfun.com/sparkfun-qwiic-oled-1-3in-128x64.html)
- [SparkFun Qwiic OLED Display (1.5 in., 128x128) - SparkFun Electronics](https://www.sparkfun.com/sparkfun-qwiic-oled-display-1-5-in-128x128.html)
- [GitHub PicoBuck: Three-channel current driver for LEDs](https://github.com/sparkfun/PicoBuck)

## Adafruit References

- [Learn Adafruit I2C Quad Rotary Encoder Breakout](https://learn.adafruit.com/adafruit-i2c-quad-rotary-encoder-breakout)
- [Learn Adafruit I2C QT Rotary Encoder](https://learn.adafruit.com/adafruit-i2c-qt-rotary-encoder/overview)
- [Adafruit I2C Stemma QT Rotary Encoder Breakout with NeoPixel](https://www.adafruit.com/product/4991)
- [Adafruit I2C Stemma QT Rotary Encoder Breakout with Encoder](https://www.adafruit.com/product/5880)
- [Adafruit I2C Quad Rotary Encoder Breakout with NeoPixel](https://www.adafruit.com/product/5752)
- [Black Nylon Machine Screw and Stand-off Set – M2.5 Thread](https://www.adafruit.com/product/3299)
- [Adafruit Swirly Aluminum Mounting Grid for 0.1 Spaced PCBs](https://www.adafruit.com/product/5781)
- [STEMMA QT / Qwiic JST SH 4-pin Cable with Premium Female Sockets - 150mm Long](https://www.adafruit.com/product/4397)
- [Adafruit Mini I2C Gamepad with seesaw](https://www.adafruit.com/product/5743)
- [Adafruit EMC2101 I2C PC Fan Controller and Temperature Sensor](https://www.adafruit.com/product/4808)
- [JST PH 2mm 4-pin Vertical Connector (10-pack)](https://www.adafruit.com/product/4390)
- [2-Axis Joystick : Adafruit Industries, Unique & fun DIY electronics and kits](https://www.adafruit.com/product/245)
- [Analog 2-axis Thumb Joystick with Select Button + Breakout Board](https://www.adafruit.com/product/512)
- [Monochrome 0.96 128x64 OLED Graphic Display](https://www.adafruit.com/product/326)
- [Adafruit Monochrome 1.12 128x128 OLED Graphic Display](https://www.adafruit.com/product/5297)

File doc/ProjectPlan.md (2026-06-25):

# Project Plan

## Specifications

- [x] Check / Update the MHLSpec_v2.md file.

## Hardware

Build the prototype using the MHLSpec_v2.md file.

- [ ] Mount the ESP32-S3-DevKitC-1 board on the prototype board using male/female headers.
- [ ] Mount the PicoBuck converter on the prototype board.
- [ ] Solder and connect a QWIIC connector to the ESP32-S3-DevKitC-1 board.
- [ ] Connect the power supply (5V and GND) to the PicoBuck converters.
- [ ] Connect the input of the PicoBuck converters to the ESP32-S3-DevKitC-1 board.
  - [ ] TBD list of pins used for LED: 8 (outer ring) using LEDC channels, one (central) using SDM
- [ ] Connect the output of the PicoBuck converters to the LEDs.

## Setup Software Development Environment

Software development for the ESP32-S3 will be done using the **ESP-IDF** framework inside **Visual Studio Code** (or the Devon/VS Code-based environment). The steps below describe the Windows installation procedure.

Reference: <https://docs.espressif.com/projects/esp-idf/en/latest/esp32s3/get-started/windows-setup.html>
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

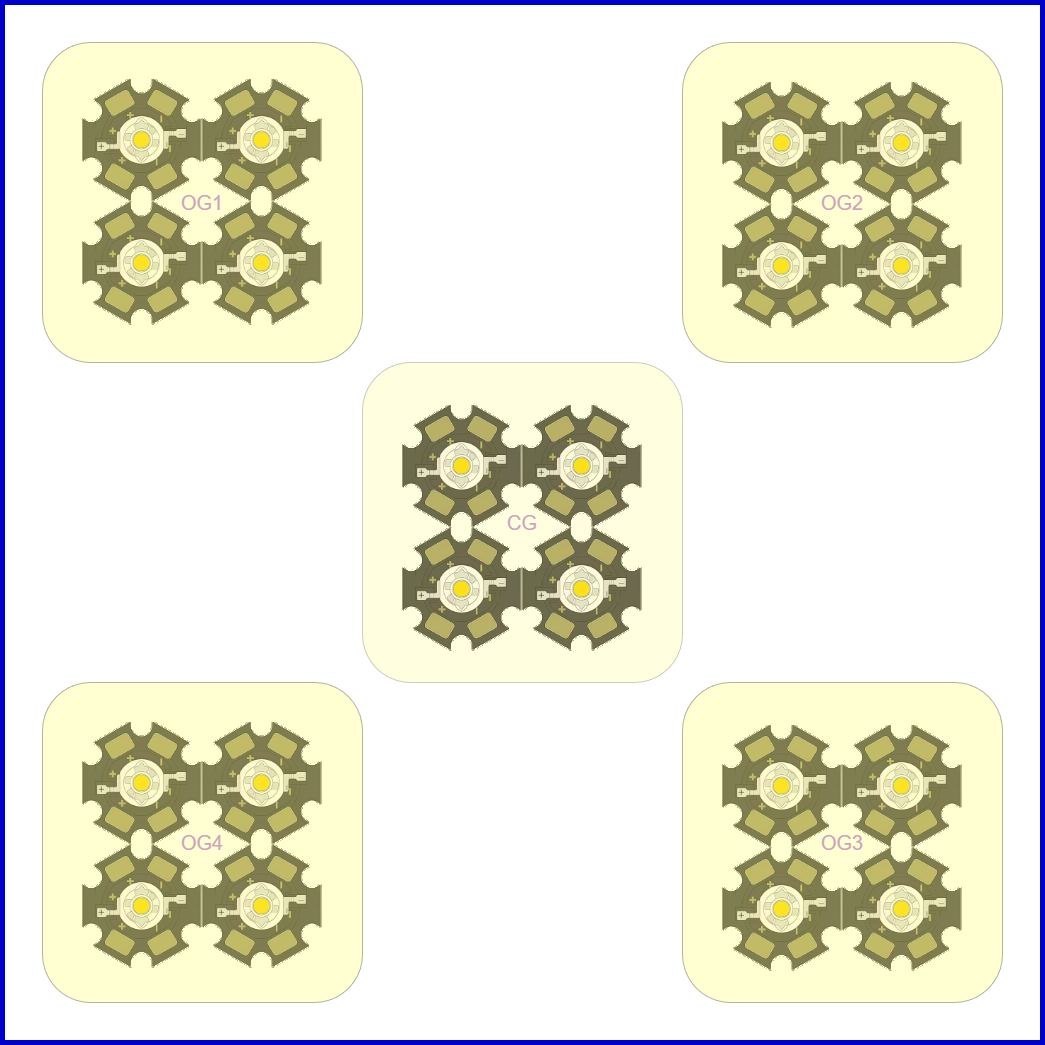
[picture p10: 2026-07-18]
doc/images/pcbled_5g.drawio.png

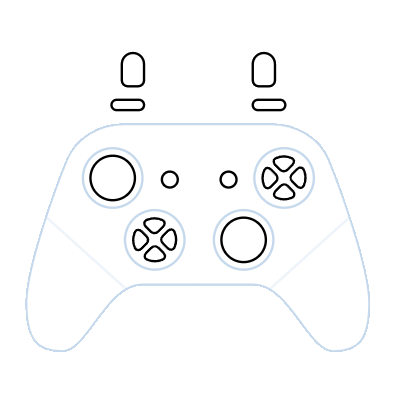
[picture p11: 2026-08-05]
MorpheusHypno/MPHEditor/Resources/Images/gamepad.png

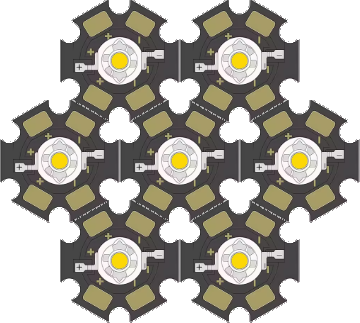
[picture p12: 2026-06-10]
doc/images/7_led_array.png

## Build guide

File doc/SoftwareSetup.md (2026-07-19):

# Setup Software Development Environment

Software development for the ESP32-S3 will be done using the **ESP-IDF** framework inside **Visual Studio Code** (or the Devon/VS Code-based environment). The steps below describe the Windows installation procedure.

Reference: <https://docs.espressif.com/projects/esp-idf/en/latest/esp32s3/get-started/windows-setup.html>

> **Note:** The current Espressif documentation recommends the **ESP-IDF Installation Manager (EIM)** instead of the older standalone installer. As of June 2026, the EIM installs ESP-IDF **v6.0.1** by default.

## Prerequisites

- [x] Windows 10 or 11 (64-bit)
- [x] Git for Windows (from <https://git-scm.com/download/win>)
- [x] Python 3.11 or later (the installer can also embed Python automatically)
- [ ] USB cable to connect the ESP32-S3-DevKitC-1 board
- [ ] USB-to-UART driver for the ESP32-S3 DevKit (usually CP210x or CH340; Windows Update often installs it automatically)

## Step 1: Download the ESP-IDF Installation Manager (EIM)

1. Go to the EIM download page: <https://dl.espressif.com/dl/eim/>
2. Download the Windows installer for the **ESP-IDF Installation Manager** (e.g., `eim-gui-windows-x64.exe`).
3. Double-click the installer to start it.

## Step 2: Install ESP-IDF with the EIM

### GUI installation (recommended)

1. Launch the **ESP-IDF Installation Manager** after installation.
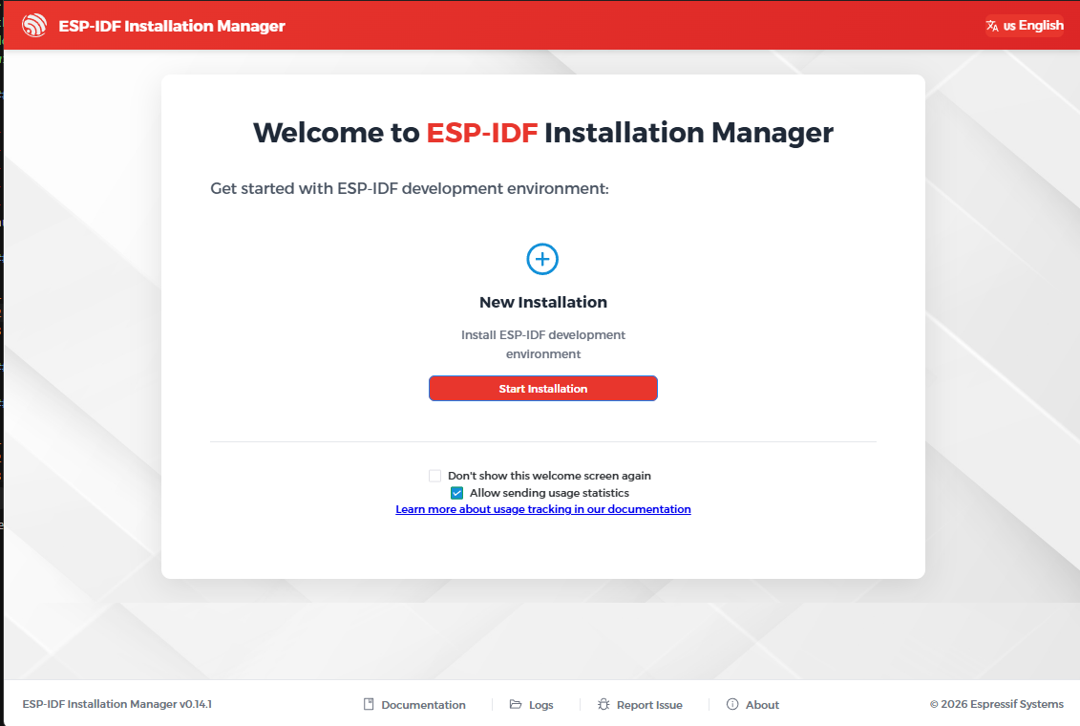
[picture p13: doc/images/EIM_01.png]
EIM
   

2. Select **Easy Installation** to install the latest stable ESP-IDF release with default settings.
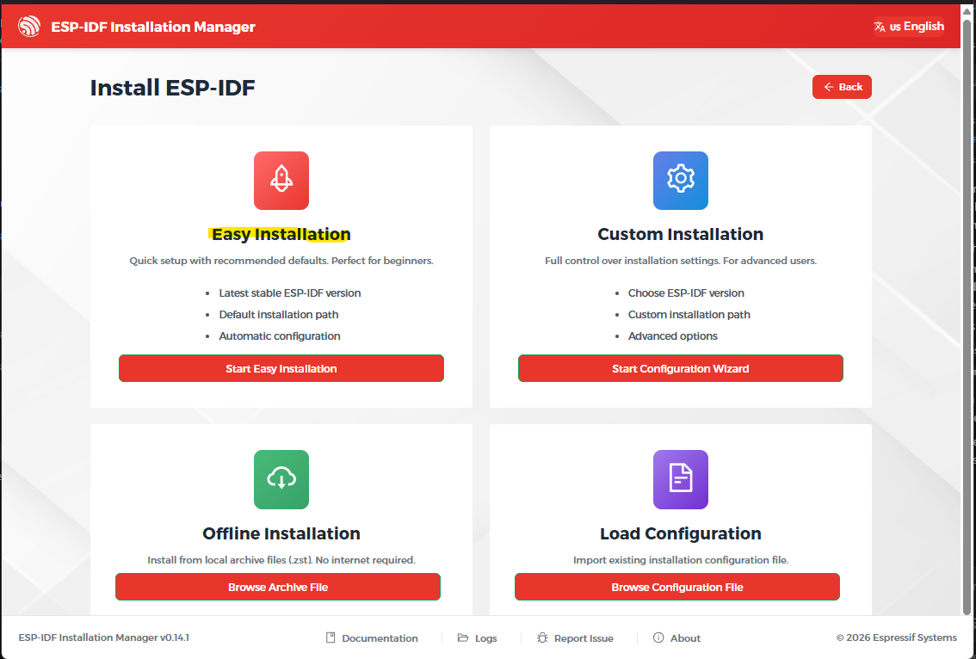
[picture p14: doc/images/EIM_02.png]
Easy Install
   

3. Wait for the download and installation to complete.
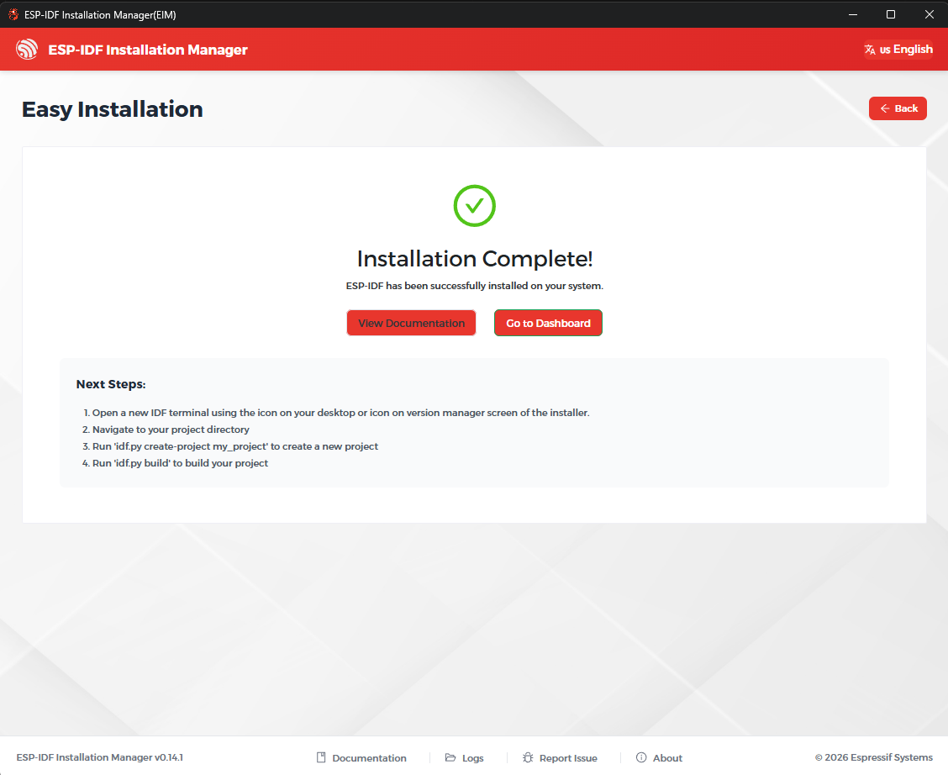
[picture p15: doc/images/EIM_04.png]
Install Complete
   

The EIM will install:

- ESP-IDF source code
- Embedded Python
- Cross-compiler toolchains
- CMake and Ninja build tools
- OpenOCD debugger
- Required Python packages

## Step 3: Verify the Installation from the ESP-IDF Command Prompt

1. After installation, open the **ESP-IDF Command Prompt** shortcut (created in the Start menu).
2. Run the following command to verify that the tools are available:

   ```cmd
   idf.py --version
   ```

   It should display the ESP-IDF version (e.g., `ESP-IDF v6.0.1`).
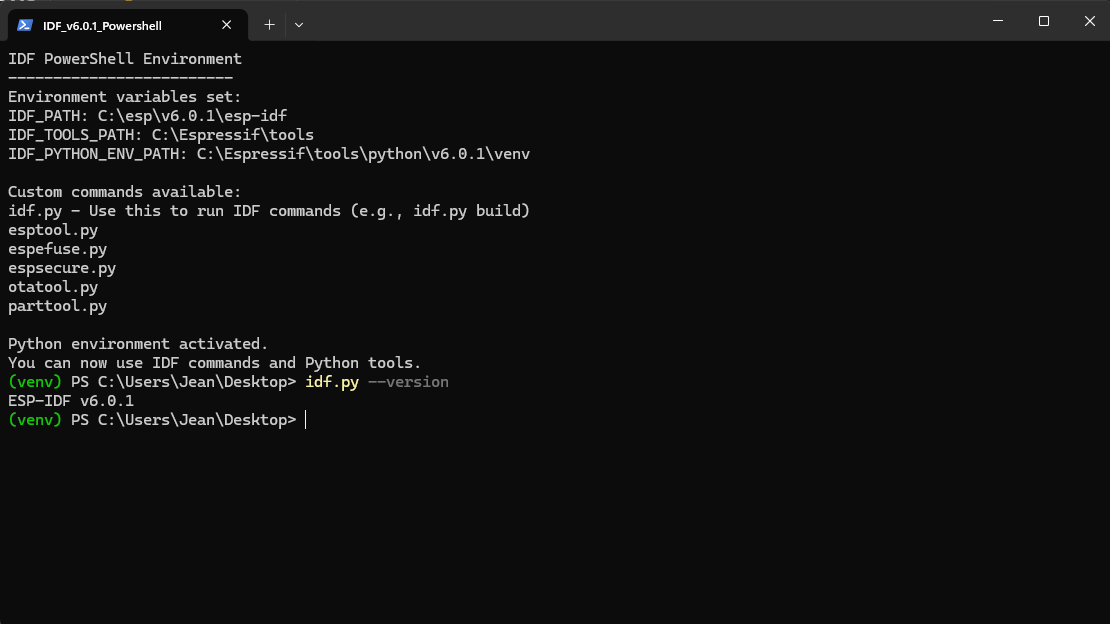
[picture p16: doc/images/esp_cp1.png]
esp version
   
3. Build a sample project to confirm everything works:

   ```cmd
   cd C:\esp\v6.0.1\esp-idf\examples\get-started\hello_world
   idf.py set-target esp32s3
   idf.py build
   ```

## Step 4: Install the ESP-IDF Extension in Visual Studio Code

1. Open **Visual Studio Code**.
2. Go to the **Extensions** view (Ctrl+Shift+X).
3. Search for **ESP-IDF** and install the official extension by **Espressif Systems**.
4. After installation, the extension usually detects the ESP-IDF environment automatically if it was installed with the EIM. If a configuration prompt appears, follow it; otherwise, open the Command Palette (Ctrl+Shift+P) and run: **ESP-IDF: Configure ESP-IDF Extension**.
5. If the extension asks for the installation folders, select:
   - ESP-IDF directory: `C:\esp\v6.0.1\esp-idf`
   - Tools directory: `C:\Users\<username>\.espressif`
6. Wait for the extension to finish the setup.
7. Open the Command Palette (Ctrl+Shift+P) and run: **ESP-IDF: Select current ESP-IDF version**. Choose the version installed by the EIM (e.g., **v6.0.1**).
8. If prompted, install the **clangd** extension (LLVM) for C/C++ code completion and navigation.

## Step 5: Flash the [Hello World Example](https://github.com/espressif/esp-idf/tree/master/examples/get-started/hello_world) from VS Code

> **USB port:** The ESP32-S3-DevKitC-1 has two USB connectors. Always use the **`UART`** port (CP2102N USB-to-UART bridge) for flashing and monitoring. The `USB` port (native USB) is for DFU/JTAG and requires additional setup.
>
> **Driver:** The `UART` port requires the **CP210x** driver from Silicon Labs. Windows Update usually installs it automatically; if a yellow exclamation mark appears in Device Manager, download it from <https://www.silabs.com/developers/usb-to-uart-bridge-vcp-drivers>. After connecting the board, a `COMx` entry should appear under **Ports (COM & LPT)**.

1. In VS Code, open the folder:
   - `C:\esp\v6.0.1\esp-idf\examples\get-started\hello_world`
2. Open the Command Palette and run: **ESP-IDF: Set Espressif Device Target**.
3. Select **ESP32-S3**. When prompted for the OpenOCD configuration, choose **`ESP32-S3 chip (via builtin USB-JTAG)`** (this is the correct option for the DevKitC-1; the ESP-PROG options are for external JTAG adapters on custom PCBs).
4. Connect the ESP32-S3-DevKitC-1 board to the computer via the **`UART`** USB port.
5. Run: **ESP-IDF: Select Flash Method** and choose **`UART`**.
6. Run: **ESP-IDF: Build your Project**.
7. Run: **ESP-IDF: Select Port to Use** and choose the `COMx` port corresponding to the ESP32-S3 (visible in Device Manager).
8. Run: **ESP-IDF: Flash your Project**.
9. Run: **ESP-IDF: Monitor your Device** to view the serial output.

## Step 5b: Build and Flash the Morpheus HypnoLight Firmware from VS Code

Because the ESP-IDF project lives in the `firmware/` subdirectory (not at the repository root), some ESP-IDF Explorer commands may not work directly. The recommended workflow is to use the **Open ESP-IDF Terminal** command.

1. In VS Code, open the Command Palette (`Ctrl+Shift+P`) and run: **ESP-IDF: Open ESP-IDF Terminal**.
   - This opens a new terminal with the ESP-IDF environment and Python virtual environment already loaded.
2. In the terminal, navigate to the firmware directory:

   ```powershell
   cd D:\Projects\DreamMachine\MorpheusHypnoLight\firmware
   ```

3. Set the target and build:

   ```powershell
   idf.py set-target esp32s3
   idf.py build
   ```

4. Flash and monitor the device:

   ```powershell
   idf.py -p COMx flash monitor
   ```

   Replace `COMx` with the port shown in Device Manager (e.g., `COM3`).

> **Note:** If the ESP-IDF Explorer commands (Build Project, Flash Device, Monitor Device, etc.) appear to do nothing, it is because the extension is looking for the project at the workspace root. Use the ESP-IDF Terminal workflow above instead.
>
> **Monitor exit:** To exit `idf.py monitor`, press `Ctrl+]` or use the sequence `Ctrl+T` then `Ctrl+X`. On AZERTY keyboards, `Ctrl+T` followed by `Ctrl+X` is usually easier than `Ctrl+]`. You may need to repeat the sequence once or twice.

## Step 6: Create the Morpheus HypnoLight Project

1. In VS Code, run: **ESP-IDF: Create New Empty Project**.
2. Choose `D:\Projects\DreamMachine\MorpheusHypnoLight` as the parent directory and name the project `firmware`. This creates the folder `firmware/` inside the repository root.
3. Set the target to **ESP32-S3**.
4. Verify the build with `idf.py build` from the integrated terminal or from the ESP-IDF Command Prompt.

### Project Directory Structure

The ESP-IDF project lives in the `firmware/` subdirectory of the repository. Keeping it in a subdirectory (rather than at the repository root) prevents the large `build/` output folder from cluttering the rest of the project.

```text
MorpheusHypnoLight/
├── doc/                        ← specifications and documentation
├── sim/                        ← simulation / PC-side tools
└── firmware/                   ← ESP-IDF project root
    ├── CMakeLists.txt          ← project declaration
    ├── sdkconfig               ← generated by menuconfig, committed to git
    ├── sdkconfig.defaults      ← optional baseline config
    ├── main/                   ← application entry point
    │   ├── CMakeLists.txt
    │   └── main.c              ← app_main(): top-level initialization
    ├── components/             ← reusable application components
    │   ├── oscillator/         ← software oscillator engine (LEDC PWM)
    │   │   ├── CMakeLists.txt
    │   │   ├── oscillator.h
    │   │   └── oscillator.c
    │   ├── led_control/        ← fixed LEDC channel output
    │   │   ├── CMakeLists.txt
    │   │   ├── led_control.h
    │   │   └── led_control.c
    │   ├── sequence/           ← sequence engine (steps, interpolation, LFO)
    │   │   ├── CMakeLists.txt
    │   │   ├── sequence.h
    │   │   └── sequence.c
    │   └── comms/              ← BLE / Wi-Fi communication layer
    │       ├── CMakeLists.txt
    │       ├── comms.h
    │       └── comms.c
    └── build/                  ← generated by idf.py build, gitignored
```

Each component under `components/` is an independent library with its own `CMakeLists.txt`. This maps directly to the modules described in `MHLSpecification.md`.

> **Note:** Add `firmware/build/` to `.gitignore` to avoid committing the several hundred MB of build artefacts.

## Additional Notes

- Keep installation paths under 90 characters and avoid spaces or special characters.
- If the ESP-IDF Command Prompt is not available, open a regular PowerShell or Command Prompt, navigate to the ESP-IDF directory, and run `export.ps1` or `export.bat` to activate the environment.
- The same setup applies to the Devon/VS Code-based environment; once the ESP-IDF extension is configured, the workflow is identical.

Once the firmware is built and flashed, the next step is to test the LED outputs with the simple LEDC test program in `firmware/main/main.c`.

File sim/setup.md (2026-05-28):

# Setup environment

```bash
# create virtual environment
python -m venv .venv
# activate virtual environment
.\.venv\Scripts\Activate.ps1
# upgrade pip
python -m pip install --upgrade pip
#install packages
pip install jupyter numpy matplotlib plotly ipywidgets pandas ipykernel
# create jupyter kernel
python -m ipykernel install --user --name=morpheus-hypnolight --display-name="Python (MorpheusHypnoLight)"
pip list

.\.venv\Scripts\python.exe -m jupyter notebook --notebook-dir="D:\Projects\DreamMachine\MorpheusHypnoLight\Simulator"
```

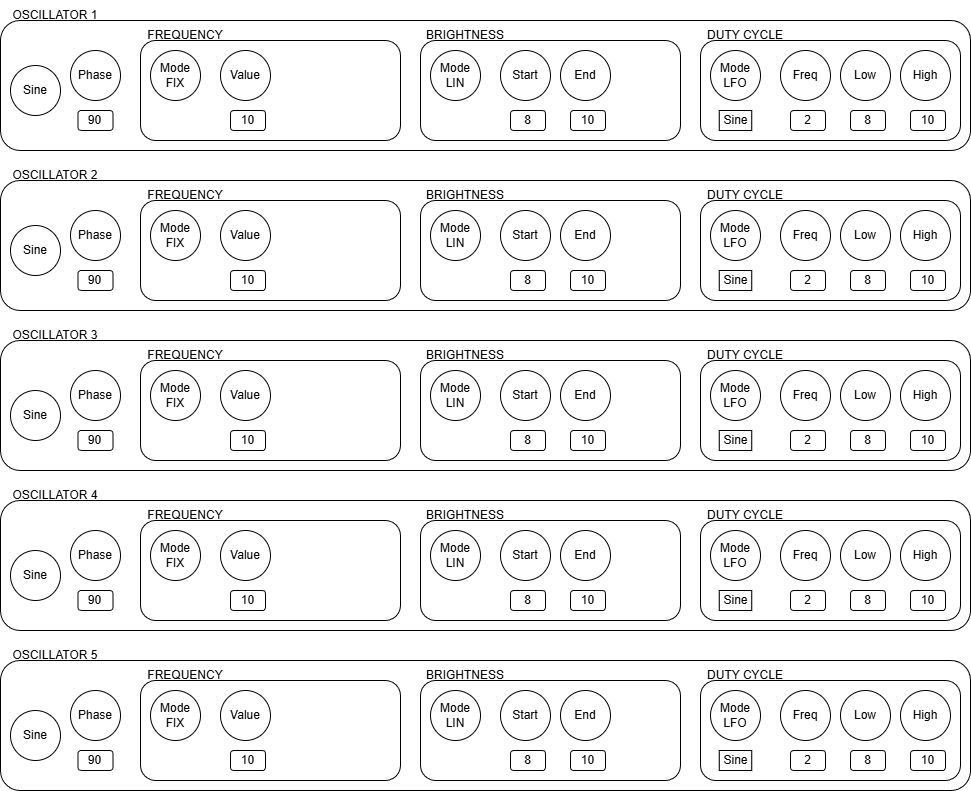
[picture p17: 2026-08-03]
doc/images/step_object.drawio.png

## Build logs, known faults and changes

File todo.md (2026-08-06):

# Things to do

What we need to do:

- [ ] Add user rating on MainPage

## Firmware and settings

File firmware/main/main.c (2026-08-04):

/*
 * Sequence playback demo for the Morpheus HypnoLight prototype.
 *
 * This program initializes the LED hardware, runs the legacy hardware tests
 * stored in test.c, loads a short sequence, starts playback, and then opens
 * an interactive console so start/stop/pause/seek commands can be sent from
 * the serial terminal.
 */

#include <math.h>
#include <stdio.h>
#include <stdlib.h>
#include <string.h>

#include "ble.h"
#include "esp_console.h"
#include "esp_err.h"
#include "esp_log.h"
#include "esp_timer.h"
#include "led_control.h"
#include "led_engine.h"
#include "oscillator.h"
#include "sequence.h"
#include "test.h"
#include "test_sequence_compact_data.h"

static const char *TAG = "sequence_demo";

#define OSCILLATOR_TICK_PERIOD_US 1000

/**
 * @brief Generate waveform samples and apply them to the LED outputs.
 *
 * This 1 kHz timer callback feeds the led_engine; the sequence component uses
 * its own timer to advance steps.
 *
 * @param[in] arg Unused esp_timer callback argument.
 */
static void oscillator_timer_callback(void *arg) {
  (void)arg;

  ESP_ERROR_CHECK(led_engine_tick());
}

/* --- Console commands ---------------------------------------------------- */

static int cmd_sequence_play(int argc, char **argv) {
  (void)argc;
  (void)argv;

  const esp_err_t error = sequence_play();
  if (error != ESP_OK) {
    printf("sequence_play failed: %d\n", error);
    return 1;
  }
  printf("sequence playing\n");
  return 0;
}

static int cmd_sequence_pause(int argc, char **argv) {
  (void)argc;
  (void)argv;

  const esp_err_t error = sequence_pause();
  if (error != ESP_OK) {
    printf("sequence_pause failed: %d\n", error);
    return 1;
  }
  printf("sequence paused\n");
  return 0;
}

static int cmd_sequence_stop(int argc, char **argv) {
  (void)argc;
  (void)argv;

  const esp_err_t error = sequence_stop();
  if (error != ESP_OK) {
    printf("sequence_stop failed: %d\n", error);
    return 1;
  }

  printf("sequence stopped\n");
  return 0;
}

static int cmd_sequence_seek(int argc, char **argv) {
  if (argc < 2) {
    printf("Usage: seek <position_ms>\n");
    return 1;
  }

  const uint32_t position_ms = (uint32_t)strtoul(argv[1], NULL, 10);
  const esp_err_t error = sequence_seek(position_ms);
  if (error != ESP_OK) {
    printf("sequence_seek failed: %d\n", error);
    return 1;
  }
  printf("sequence seeked to %lu ms (step %lu)\n", (unsigned long)position_ms,
         (unsigned long)sequence_get_current_step());
  return 0;
}

static int cmd_sequence_status(int argc, char **argv) {
  (void)argc;
  (void)argv;

  const uint32_t current_step = sequence_get_current_step();
  const uint32_t step_count = sequence_get_step_count();
  const uint32_t elapsed_in_step = sequence_get_elapsed_ms();
  const uint32_t total_elapsed = sequence_get_total_elapsed_ms();

  printf("playing: %s, step: %lu/%lu, elapsed in step: %lu ms, total: %lu ms\n",
         sequence_is_playing() ? "yes" : "no", (unsigned long)current_step + 1U,
         (unsigned long)step_count, (unsigned long)elapsed_in_step,
         (unsigned long)total_elapsed);
  return 0;
}

static int cmd_brightness(int argc, char **argv) {
  if (argc < 2) {
    printf("Usage: bright <value>\n");
    printf("Current global brightness: %.2f\n",
           (double)led_control_get_global_brightness());
    return 1;
  }

  const float brightness = strtof(argv[1], NULL);
  if (!isfinite(brightness) || brightness < 0.0f || brightness > 1.0f) {
    printf("Brightness must be between 0.0 and 1.0\n");
    return 1;
  }

  const esp_err_t error = led_control_set_global_brightness(brightness);
  if (error != ESP_OK) {
    printf("led_control_set_global_brightness failed: %d\n", error);
    return 1;
  }

  printf("Global brightness set to %.2f\n", (double)brightness);
  return 0;
}

static int cmd_run_tests(int argc, char **argv) {
  (void)argc;
  (void)argv;

  /* test_run_all receives the oscillator timer so it can start/stop the
   * 1 kHz led_engine tick during the visual tests. */
  extern esp_timer_handle_t g_oscillator_timer;
  printf("Running hardware tests...\n");
  test_run_all(g_oscillator_timer);
  printf("Hardware tests complete\n");

  /* Restart the led_engine tick for sequence playback. */
  ESP_ERROR_CHECK(
      esp_timer_start_periodic(g_oscillator_timer, OSCILLATOR_TICK_PERIOD_US));
  return 0;
}

static int cmd_sequence_size(int argc, char **argv) {
  (void)argc;
  (void)argv;

  const uint32_t step_count = sequence_get_step_count();
  const size_t one_step = sizeof(sequence_step_t);
  const size_t one_oscillator = sizeof(sequence_oscillator_step_t);
  const size_t one_modulator = sizeof(modulator_config_t);
  const size_t all_steps = one_step * step_count;
  const size_t max_sequence = one_step * SEQUENCE_MAX_STEPS;

  printf("sequence_step_t:         %zu bytes\n", one_step);
  printf("sequence_oscillator_step_t: %zu bytes\n", one_oscillator);
  printf("modulator_config_t:      %zu bytes\n", one_modulator);
  printf("loaded steps:            %lu\n", (unsigned long)step_count);
  printf("loaded sequence RAM:     %zu bytes\n", all_steps);
  printf("max sequence RAM:      %zu bytes\n", max_sequence);
  printf("compact demo bytes:      %zu bytes\n", sizeof(demo_sequence_compact));
  return 0;
}

static void register_sequence_commands(void) {
  const esp_console_cmd_t commands[] = {
      {
          .command = "play",
          .help = "Start or resume sequence playback",
          .hint = NULL,
          .func = &cmd_sequence_play,
      },
      {
          .command = "pause",
          .help = "Pause sequence playback",
          .hint = NULL,
          .func = &cmd_sequence_pause,
      },
      {
          .command = "stop",
          .help = "Stop playback and return to the beginning",
          .hint = NULL,
          .func = &cmd_sequence_stop,
      },
      {
          .command = "seek",
          .help = "Seek to an absolute position in milliseconds",
          .hint = "<position_ms>",
          .func = &cmd_sequence_seek,
      },
      {
          .command = "status",
          .help = "Show playback status and current step",
          .hint = NULL,
          .func = &cmd_sequence_status,
      },
      {
          .command = "bright",
          .help = "Set global brightness multiplier (0.0 to 1.0)",
          .hint = "<brightness>",
          .func = &cmd_brightness,
      },
      {
          .command = "tests",
          .help = "Run the hardware tests stored in test.c",
          .hint = NULL,
          .func = &cmd_run_tests,
      },
      {
          .command = "size",
          .help = "Show structure sizes and memory footprint",
          .hint = NULL,
          .func = &cmd_sequence_size,
      },
  };

  for (size_t i = 0; i < sizeof(commands) / sizeof(commands[0]); i++) {
    ESP_ERROR_CHECK(esp_console_cmd_register(&commands[i]));
  }
}

/* Global handle used by console commands and the demo setup. */
esp_timer_handle_t g_oscillator_timer = NULL;

void app_main(void) {
  ESP_LOGI(TAG, "Initializing LED hardware");
  ESP_ERROR_CHECK(led_control_init());
  ESP_ERROR_CHECK(
      led_control_set_global_brightness(0.6f)); /* limit eye strain */
  ESP_ERROR_CHECK(led_engine_init());
  ESP_ERROR_CHECK(led_control_all_off());

  const esp_timer_create_args_t oscillator_timer_args = {
      .callback = oscillator_timer_callback,
      .arg = NULL,
      .name = "led_engine_tick",
  };
  ESP_ERROR_CHECK(
      esp_timer_create(&oscillator_timer_args, &g_oscillator_timer));

  ESP_ERROR_CHECK(test_validate_compact_sequence());

  /* Optional: run the legacy hardware tests once before the demo starts.
   * If enabled, test_run_all() stops the oscillator timer, so restart it
   * afterwards with esp_timer_start_periodic(). */
  // test_run_all(g_oscillator_timer);
  // ESP_ERROR_CHECK(
  //     esp_timer_start_periodic(g_oscillator_timer,
  //     OSCILLATOR_TICK_PERIOD_US));

  ESP_LOGI(TAG, "Loading compact demo sequence");
  ESP_ERROR_CHECK(sequence_init());
  ESP_ERROR_CHECK(test_load_compact_demo_sequence());

  ESP_LOGI(TAG, "Starting 1 kHz led_engine tick");
  ESP_ERROR_CHECK(
      esp_timer_start_periodic(g_oscillator_timer, OSCILLATOR_TICK_PERIOD_US));

  ESP_ERROR_CHECK(sequence_play());

  ESP_LOGI(TAG, "Starting BLE peripheral");
  ESP_ERROR_CHECK(ble_init());

  ESP_LOGI(TAG, "Sequence started. Open the serial console and type help for "
                "commands (play, pause, stop, seek, status, tests).");

  /* Interactive console. */
  esp_console_repl_t *repl = NULL;
  esp_console_repl_config_t repl_config = ESP_CONSOLE_REPL_CONFIG_DEFAULT();
  esp_console_dev_uart_config_t uart_config =
      ESP_CONSOLE_DEV_UART_CONFIG_DEFAULT();
  ESP_ERROR_CHECK(esp_console_new_repl_uart(&uart_config, &repl_config, &repl));
  ESP_ERROR_CHECK(esp_console_register_help_command());
  register_sequence_commands();
  ESP_ERROR_CHECK(esp_console_start_repl(repl));
}

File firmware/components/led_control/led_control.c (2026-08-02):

/**
 * @file led_control.c
 * @brief LEDC-backed implementation of the fixed HypnoLight LED outputs.
 */
#include "led_control.h"

#include <math.h>

#include "driver/ledc.h"
#include "freertos/FreeRTOS.h"
#include "freertos/task.h"

/** @brief Serialized access to the global brightness multiplier. */
static portMUX_TYPE led_control_lock = portMUX_INITIALIZER_UNLOCKED;

/** @brief Global brightness multiplier applied to every channel. */
static float led_control_global_brightness =
    LED_CONTROL_DEFAULT_GLOBAL_BRIGHTNESS;

/** @brief LEDC timer shared by all five LED output channels. */
#define LED_CONTROL_TIMER LEDC_TIMER_0

/** @brief LEDC speed mode supported by the ESP32-S3. */
#define LED_CONTROL_MODE LEDC_LOW_SPEED_MODE

/** @brief Fixed PWM carrier frequency for all LED control outputs. */
#define LED_CONTROL_FREQUENCY_HZ 1000

/** @brief LEDC duty resolution used for brightness control. */
#define LED_CONTROL_RESOLUTION LEDC_TIMER_10_BIT

/** @brief Maximum duty value represented by LED_CONTROL_RESOLUTION. */
#define LED_CONTROL_MAX_DUTY ((1U << LED_CONTROL_RESOLUTION) - 1U)

/** @brief Gamma correction exponent to linearize perceived brightness. */
#define LED_CONTROL_GAMMA 2.2f

/**
 * @brief Brightness value below which a linear lift is applied.
 *
 * Below this threshold the gamma curve compresses values so much that LEDs
 * stay dark. The lift ramps linearly from 0 at brightness 0 up to
 * LED_CONTROL_LOW_END_LIFT at this threshold, then stays constant.
 */
#define LED_CONTROL_LOW_END_THRESHOLD 0.02f

/**
 * @brief Output lift applied at the low-end brightness threshold.
 *
 * This duty offset is added after gamma correction to make the LED turn-on
 * point occur at approximately LED_CONTROL_LOW_END_THRESHOLD for all global
 * dimmer settings. It is intentionally small so it does not dominate at higher
 * brightness values and the global dimmer remains effective.
 */
#define LED_CONTROL_LOW_END_LIFT 0.005f

/** @brief GPIO mapping indexed by fixed oscillator ID. */
static const int led_control_gpios[LED_CONTROL_OSCILLATOR_COUNT] = {
    4, 5, 6, 7, 15,
};

/**
 * @brief Clamp a finite value to the normalized brightness range.
 *
 * @param[in] value Value to clamp.
 *
 * @return value constrained to the inclusive range [0.0, 1.0].
 */
static float clamp_unit(float value) {
  if (value <= 0.0f) {
    return 0.0f;
  }
  if (value >= 1.0f) {
    return 1.0f;
  }
  return value;
}

esp_err_t led_control_init(void) {
  const ledc_timer_config_t timer_config = {
      .speed_mode = LED_CONTROL_MODE,
      .duty_resolution = LED_CONTROL_RESOLUTION,
      .timer_num = LED_CONTROL_TIMER,
      .freq_hz = LED_CONTROL_FREQUENCY_HZ,
      .clk_cfg = LEDC_AUTO_CLK,
  };

  taskENTER_CRITICAL(&led_control_lock);
  led_control_global_brightness = LED_CONTROL_DEFAULT_GLOBAL_BRIGHTNESS;
  taskEXIT_CRITICAL(&led_control_lock);

  esp_err_t error = ledc_timer_config(&timer_config);
  if (error != ESP_OK) {
    return error;
  }

  for (uint8_t oscillator_id = 0; oscillator_id < LED_CONTROL_OSCILLATOR_COUNT;
       oscillator_id++) {
    const ledc_channel_config_t channel_config = {
        .gpio_num = led_control_gpios[oscillator_id],
        .speed_mode = LED_CONTROL_MODE,
        .channel = (ledc_channel_t)oscillator_id,
        .timer_sel = LED_CONTROL_TIMER,
        .duty = 0,
        .hpoint = 0,
    };

    error = ledc_channel_config(&channel_config);
    if (error != ESP_OK) {
      return error;
    }

    /* Explicitly latch a zero duty cycle so the channel is off before the
     * oscillator tick begins. */
    error = ledc_set_duty(LED_CONTROL_MODE, (ledc_channel_t)oscillator_id, 0);
    if (error != ESP_OK) {
      return error;
    }
    error = ledc_update_duty(LED_CONTROL_MODE, (ledc_channel_t)oscillator_id);
    if (error != ESP_OK) {
      return error;
    }
  }

  return ESP_OK;
}

esp_err_t led_control_update(uint8_t oscillator_id, float osc_value,
                             float current_brightness) {
  if (oscillator_id >= LED_CONTROL_OSCILLATOR_COUNT || !isfinite(osc_value) ||
      !isfinite(current_brightness)) {
    return ESP_ERR_INVALID_ARG;
  }

  taskENTER_CRITICAL(&led_control_lock);
  const float global_brightness = led_control_global_brightness;
  taskEXIT_CRITICAL(&led_control_lock);

  /* Apply gamma correction to the dimmed brightness and then add a small,
   * saturating low-end lift. The lift makes the LED turn-on threshold occur at
   * roughly the same brightness parameter value regardless of the global
   * dimmer, while keeping the gamma response dominant at higher brightness so
   * the global dimmer remains effective. */
  const float local_brightness = clamp_unit(current_brightness);
  const float dimmed_brightness = local_brightness * global_brightness;
  const float gamma_corrected = powf(dimmed_brightness, LED_CONTROL_GAMMA);
  const float low_end_lift =
      LED_CONTROL_LOW_END_LIFT *
      fminf(local_brightness / LED_CONTROL_LOW_END_THRESHOLD, 1.0f);
  const float blended_brightness = gamma_corrected + low_end_lift;
  const float final_brightness =
      clamp_unit(osc_value) *
      (global_brightness > 0.0f ? clamp_unit(blended_brightness) : 0.0f);
  const uint32_t duty =
      (uint32_t)(final_brightness * LED_CONTROL_MAX_DUTY + 0.5f);

  esp_err_t error =
      ledc_set_duty(LED_CONTROL_MODE, (ledc_channel_t)oscillator_id, duty);
  if (error != ESP_OK) {
    return error;
  }

  return ledc_update_duty(LED_CONTROL_MODE, (ledc_channel_t)oscillator_id);
}

esp_err_t led_control_set_global_brightness(float brightness) {
  if (!isfinite(brightness) || brightness < 0.0f || brightness > 1.0f) {
    return ESP_ERR_INVALID_ARG;
  }

  taskENTER_CRITICAL(&led_control_lock);
  led_control_global_brightness = brightness;
  taskEXIT_CRITICAL(&led_control_lock);

  return ESP_OK;
}

float led_control_get_global_brightness(void) {
  taskENTER_CRITICAL(&led_control_lock);
  const float value = led_control_global_brightness;
  taskEXIT_CRITICAL(&led_control_lock);

  return value;
}

esp_err_t led_control_all_off(void) {
  for (uint8_t oscillator_id = 0; oscillator_id < LED_CONTROL_OSCILLATOR_COUNT;
       oscillator_id++) {
    const esp_err_t error = led_control_update(oscillator_id, 0.0f, 0.0f);
    if (error != ESP_OK) {
      return error;
    }
  }

  return ESP_OK;
}

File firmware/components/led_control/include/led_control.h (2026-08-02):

/**
 * @file led_control.h
 * @brief Fixed LEDC output control for the Morpheus HypnoLight LED groups.
 *
 * This module maps five oscillator IDs to the fixed PWM outputs PB1 through
 * PB4 and CG. Callers provide normalized waveform and brightness values; the
 * module combines them and writes the resulting duty cycle to LEDC.
 */
#pragma once

#include <stdint.h>

#include "esp_err.h"

/** @brief Number of peripheral LED banks controlled by PB1 through PB4. */
#define LED_CONTROL_PERIPHERAL_BANK_COUNT 4

/** @brief Total number of LED groups and fixed LEDC output channels. */
#define LED_CONTROL_OSCILLATOR_COUNT 5

/** @brief Oscillator ID assigned to the central group (CG). */
#define LED_CONTROL_CG_OSCILLATOR_ID 4

/** @brief Default global brightness multiplier applied to every channel. */
#define LED_CONTROL_DEFAULT_GLOBAL_BRIGHTNESS 1.0f

/**
 * @brief Configure the LEDC timer and all five fixed LED output channels.
 *
 * The function initializes each channel with a zero duty cycle. It must be
 * called before any call to led_control_update() or led_control_all_off().
 *
 * @return ESP_OK on success; otherwise, an error returned by the LEDC driver.
 */
esp_err_t led_control_init(void);

/**
 * @brief Update one LED group's duty cycle from normalized signal values.
 *
 * The output duty is calculated as osc_value × clamp(global_brightness ×
 * gamma(current_brightness) + low_end_lift(current_brightness)), where gamma
 * applies a perceptual correction and low_end_lift adds a small, saturating
 * offset so the LED turn-on threshold stays around the same brightness value
 * for any global dimmer setting. Finite values outside the normalized range are
 * clamped to [0.0, 1.0]. This function uses standard LEDC driver APIs and must
 * not be called from an ISR.
 *
 * @param[in] oscillator_id Fixed channel ID in the range 0 to 4.
 * @param[in] osc_value Instantaneous waveform value.
 * @param[in] current_brightness Current brightness factor after any global
 *                                brightness scaling.
 *
 * @return ESP_OK on success, ESP_ERR_INVALID_ARG for an invalid ID or a
 *         non-finite input value, or an error returned by the LEDC driver.
 */
esp_err_t led_control_update(uint8_t oscillator_id, float osc_value,
                             float current_brightness);

/**
 * @brief Set the global brightness multiplier for all channels.
 *
 * The output duty cycle is scaled by this factor, allowing the overall
 * lamp brightness to be changed with a single setting. The value must be in
 * the inclusive range [0.0, 1.0]. The default is 1.0 (no attenuation).
 *
 * @param[in] brightness Global brightness multiplier.
 *
 * @return ESP_OK on success, or ESP_ERR_INVALID_ARG for an invalid value.
 */
esp_err_t led_control_set_global_brightness(float brightness);

/**
 * @brief Return the current global brightness multiplier.
 *
 * @return Current global brightness multiplier in [0.0, 1.0].
 */
float led_control_get_global_brightness(void);

/**
 * @brief Turn off all five LED groups.
 *
 * This function writes a zero duty cycle to every fixed LEDC channel.
 *
 * @return ESP_OK on success; otherwise, the first error returned by the LEDC
 *         driver.
 */
esp_err_t led_control_all_off(void);

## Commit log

2026-06-24 Added schematic updated spec
    [HypnoLight.fzz]
2026-06-30 update spec and schematic
    [HypnoLight.fzz]
2026-07-18 Update hardware documentation with detailed wiring and component specifications
    [ControlBoard.fzz, HypnoLight.fzz]
2026-07-18 intermediate before grouping of led
    [HypnoLight.fzz]
2026-07-19 renamed OG to PB added pull down resistor on GPIO to PicoBuck
    [HypnoLight.fzz]
2026-07-19 fix clang errors 'pb include)
    [main.c]
2026-07-20 implement led_control component
2026-07-20 test oscillator in main.c
    [main.c]
2026-07-22 new/update component and soft arch - soft arch update - led_control global brightness - added led_engine component - added modulator component - update sequence and main - added doxygen configuration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
2026-07-22 add pause/resume/seek support to modulators and led_engine real play/pause functions
2026-07-22 Fix sequence & json parser for demo
    [main.c]
2026-07-22 Added gamma correction duty = brightness^2.2 bug fixes added bright command
    [led_control.c, led_control.h, main.c]
2026-07-23 Improved spec & improved led_control
2026-08-02 Add low-end lift to LED brightness calculation to maintain consistent turn-on threshold across global dimmer settings
2026-08-04 Implement realtime mode with zero-duration step support and prevent timer usage in hold state
2026-08-04 Add ValueScale property to ModulatorEditor for percentage-based value scaling and fix sequence_stop command to use dedicated stop function
    [main.c]
2026-08-05 Add collection selector to MainPage with picker for switching between MPH collections
2026-08-05 Rename Duration to DurationSeconds and change from milliseconds to seconds in SequenceMetadata
2026-08-05 Add expandable sequence list items with summary display and action buttons in MainPage
2026-08-05 Add sequence action buttons with commands for playlist, edit, and play operations, plus collection and sequence management stubs in MainViewModel
2026-08-06 Add BLE mode switching to PlayerPage and RealtimeEditorPage with automatic mode setting on page appearance
2026-08-07 Send current step and brightness to device before PLAY command to ensure editor values are synced when starting realtime playback
